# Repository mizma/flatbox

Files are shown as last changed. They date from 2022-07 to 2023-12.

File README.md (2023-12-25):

# Flatbox-ACR

_**No longer maintained.**_

**New Design is available [Here](https://github.com/mizma/ergoSHIFT/) with 11 button support and GP2040-CE firmware support planned**



_**Low profile hitbox-layout fightstick with Acrylic shell**_

This flatbox-acr design is based on [jfedor2/flatbox](https://github.com/jfedor2/flatbox) but with a few tweaks
(rev1.1 pcb has been redone from ground up):

[日本語はこちら](README_ja.md)

* Replaced the 3D printed case with Acrylic shell, allowing to insert printed artwork.
    * or marvel at the simplistic PCB...
    * Heavily inspired by y [Mille-Feuille](https://pomegd.booth.pm/items/2685530) by [@pomegd](https://twitter.com/pomegd)
* modified button layout to:
    * Accomodate for the clearance needed for acrylic cutting
    * To mimic the layout of the original Hitbox button layout(based off of official stencil)
* Silk screen update
    * Added small logo instead of text (flatbox acr)
    * added legends for each buttons (SQUARE, CIRCLE etc.)
    * moved logo to the bottom edge to minimize see-through when adding artwork on top
* Pattern changes
    * GND Fill
    * add vias to join gnd fill
    * moved traces slightly to avoid GND islands and thin GND fills
    * added reset button for Pro Micro board
* Remodeled Button Caps to accomodate for the increased case-height

Final product when assembled will look something like the following:

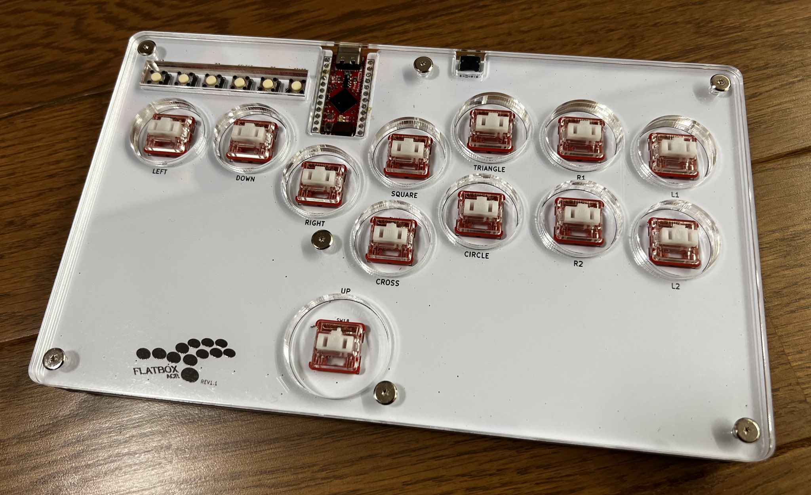
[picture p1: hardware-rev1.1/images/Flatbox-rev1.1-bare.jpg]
Assembled Flatbox


You can print any fan art using the [Stencil](hardware-rev1.1/images/Flatbox-ACR-Stencil_300dpi.png) 
to customize the looks as well.

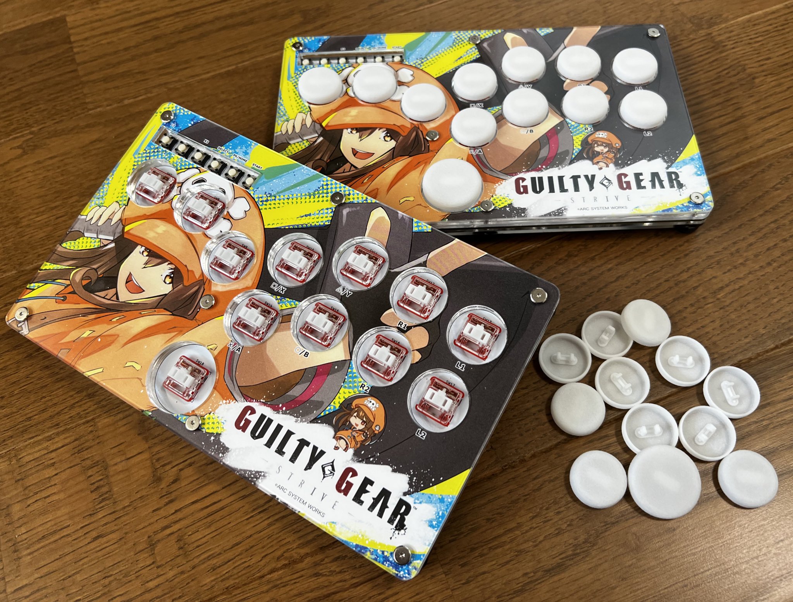
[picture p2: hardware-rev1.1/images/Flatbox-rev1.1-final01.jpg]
Assembled Flatbox with Fan Art


(*) Artwork based on a trace of In-Game Screenshot + Official Fan-kit (©ARK SYSTEM WORKS)

There is currently one revision of the Flatbox-ACR.  They all use Kailh low profile (choc v1) mechanical keyboard switches.
The table below lists their main features.  See the README for each version for details on how to make them.

version | [rev1.1](hardware-rev1.1) |
------- | ------------------------- |
case dimensions | 210x125x13.6mm |
compatibility (using provided firmware) | PC, PS3, Xinput, Switch |
add-on board | Sparkfun Qwiic Pro Micro |
onboard chip | - |
port | USB-C |
SMT assembly required | no |
firmware | [ATmega32U4](firmwares_atmega32u4) |

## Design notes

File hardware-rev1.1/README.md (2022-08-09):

# Flatbox-ACR rev1.1

[日本語はこちら](README_ja.md)

This is rev1.1 of the Flatbox-ACR. In this version an Arduino Pro Micro is soldered onto the main PCB.

To make one you will need:

* [acrylic shell](acrylic-shell)
    * Top layers in 2mm,3mm,2mm thickness
    * Bottom layers in 3mm thickness x 2
* [the Flatbox-ACR PCB](pcb)
* Arduino Pro Micro [SparkFun Qwiic Pro Micro - USB-C (ATmega32U4)](https://www.sparkfun.com/products/15795)
* 12x Kailh low profile (choc v1) switches of your choice
    * I use Kailh Choc v1 Red Pro (Linear and low activation force: 35±10gf with actuation travel: 1.5±0.5mm)
    * Light Blue (gChoc) can be used for even lower actuation force.
* (optionally) 12x Kailh low profile hotswap sockets
* [3D printed buttoncaps](../3d-printed-buttoncaps)
* 6x 6x6x5mm tact switches
    * I Used OMRON B3F-1000 but other similar products with same footprint should work
    * Selecting switches with height higher than 7mm will result in the switch extruding from the case
* 1x 3x6x4.3 horizontal tact switch
    * https://www.newegg.com/p/2S7-01KR-035X0
    * https://shop.yushakobo.jp/collections/all-keyboard-parts/products/a1600ed-01-1
    * [schematics](images/tactile-switch_3x6x4.3.jpg)
* 7x M3 screws (length 20mm)
    * Acryl top 2mm * 2 + 3mm = 7mm
    * PCB 1.6mm
    * Acryl bottom 3mm * 2 = 6mm
    * Rubber feet screw depth = 3mm (using rubber feet below.  adjust for your part)
    * Rubber feet total depth = 8mm (using rubber feet below.  adjust for your part)
    * M3 nut height = 2mm
    * min length = 19.6mm (using rubber feet below.  adjust for your part)
    * max length = 22.6mm (using rubber feet below.  adjust for your part)
* 7x M3 nut and acompanying rubber feet
    * Rubber feet Tochigiya [TM-TK-15](https://www.monotaro.com/p/0933/2486/?displayId=5)
    * The position of the holes are intended for feet radius of less than 8mm
* a soldering iron
    * something with enough power is better 
      (i.e. [Hakko FX 600](https://www.hakko.com/japan/products/hakko_fx600_set.html))
    * I recommend changin tips to D type for most Through-hole soldering, or C type if you plan to
      solder SMT as well. (default B tips are the harder to use for most PCB soldering)
    * Use 230C ~ 250C temp recommended (can be changed if you know your way around)

## Assembly Instructions

### Ordering PCB

I used [JLCPCB](https://jlcpcb.com/).  Just upload the gerber files in [pcb](pcb) and keep most parameters default.
You may change PCB Qty and PCB Color if you like.  All other parameters should be kept the same.

### Ordering 3D Printed Buttons

If you have a 3D printer, print at your own will.  Files are found [here](../3d-printed-buttoncaps/).

* [Flatbox-ACR-ButtonCapBig.stl](../3d-printed-buttoncaps/Flatbox-ACR-ButtonCapBig.stl) 
  is used for the thumb button. 1 board needs 1 of this button.
* [Flatbox-ACR-Buttoncap.stl](../3d-printed-buttoncaps/Flatbox-ACR-ButtonCapBig.stl) is used for all ther buttons.
  1 board needs 11 of this button.
* [Flatbox-ACR-FullSetButtonCaps.stl](../3d-printed-buttoncaps/Flatbox-ACR-FullSetButtonCaps.stl) is an STL file 
  containing 1 full set of buttons (11 small and 1 big.).  If your 3D printing service allows 12 or more shells,
  it may be cheaper to print in one batch using this STL file.
    * Print size needs to be bigger than X：99.0000mm x Y： 93.5000mm x Z： 6.0000mm

Insertion portion may need to be adjusted in size for your 3D Printer and settings to fit snugly to the switch.
You may use some of the printer features but if that doesn't work, you might want to edit the original model.
Model data are found in the same directory in a [FreeCAD](https://www.freecadweb.org/) file format.

Also, since the insertion portion requires a fairly tight tolerance which is not easily achieved by 3D printers.
To that extent, the models are modelled slightly on the larger side.  I have had fairly good results with 
this model using SLS Nylon print but sometimes it is too large.  Which can be filed down to fit.

#### Materials Consideration

* Nylon
    * May be a good place to start for tensile strength and good chemical stability.
    * can be pretty strong if printed using SLS process at some printing services
    * may be prone to warping.  not good for humid places.
* UV Resin
    * Also pretty strong as a material, and stronger to humidity.
    * Maybe slightly more brittle than Nylon

### Ordering Acrylic cuts

I use [Elecrow](https://www.elecrow.com/acrylic-cutting.html) to cut acrylic.

Upload the .zip file in [acrylic-shell](acrylic-shell/) to the Elecrow Acrylic cut service to order.
.Zip file includes the dxf file and the dimentions.txt file.  PDF is just for reference.

Layer 01 and 02 should be made of 3mm thickness.

For the top 3 layers, there are two options:

1. Print Layer 03 at 2mm, 04 at 2mm x 2.
    * This will produce the flatbox-acr at 13.6mm at the body (excl. rubber feet and buttons) at the cost of reset 
      switch not being covered.
2. Print Layer 03 at 2mm, 04 at 3mm and layer 05 at 2mm.
    * This will produce the flatbox-acr at 14.6mm at the body (excl. rubber feet and buttons).  Reset switch will 
      be covered at the cost of thickness and less button extrusion. (may want to tweak the button caps to have 
      more thickness)

The original design file (FreeCAD file) can be found [here](./design_data/acryl-design/).

The Acrylic should look like the following (with PCB stacked)

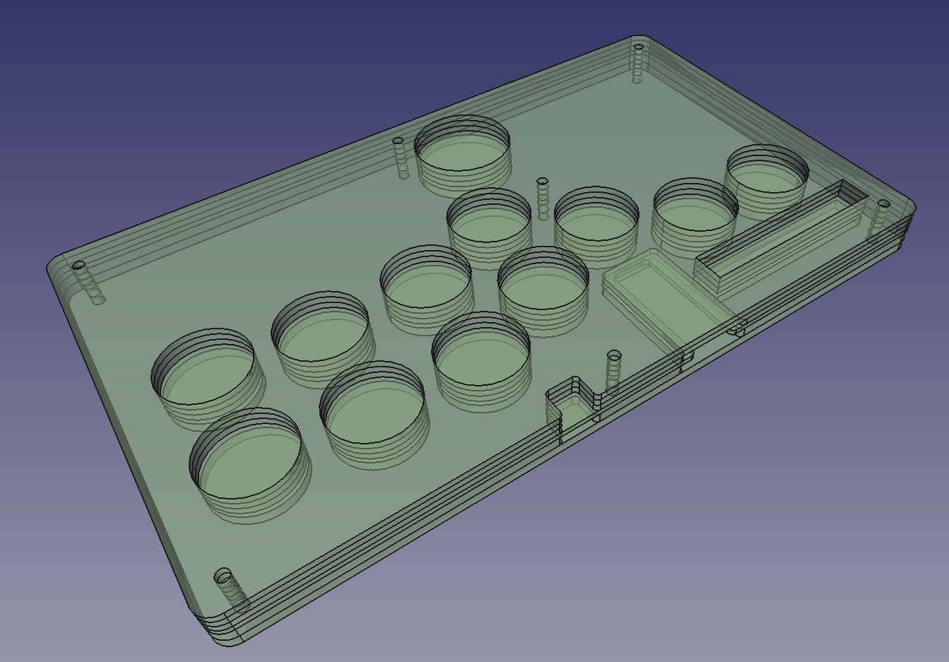
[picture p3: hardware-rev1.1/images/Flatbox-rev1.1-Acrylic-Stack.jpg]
Flatbox-rev1-Acrylic-Stack


(*) Above image uses two Layer 4 at 2mm (exposed reset switch but 1mm thinner)

### Assembly

1. Solder all the Choc v1 switches and the tactile switches.  make sure you populate the side with the logo.
    * If you populate the side with the logo, the parts only goes in in the correct orientation.
    * If you use the hot-swap sockets, those will go on the back. (see silk screen on back side for orientation)
        * For hotswap sockets, pre-solder one side of the pad on PCB, place the socket, heat the pre-solder while
          pressing down on the socket to attach the socket.  After It is attached, solder the other side fully
          and then add more solder on the pre-soldered side.
2. Solder the Pro Micro Qwiic from the bottom side of the PCB up into the slit (USB socket should be between
   the cut-outs on the board, facing up) (Following instruction is how I did it.  There may be other ways)
    1.  First, mask the back side holes on the PCB with masking tape, and poke a small hole in each Through-hole
        with a needle. (This is to stop creating solder filets on the side the ProMicro will be soldered to.
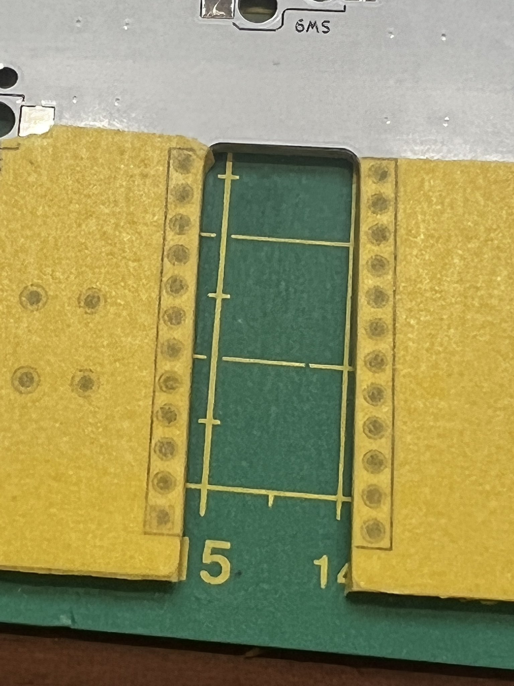
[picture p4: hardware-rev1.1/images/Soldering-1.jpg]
Mask Through-holes
        
    2. Insert a short (2~3cm) tin coated wire in the hole and solder onto the board.  Then cut the excess wire
       on the front side.
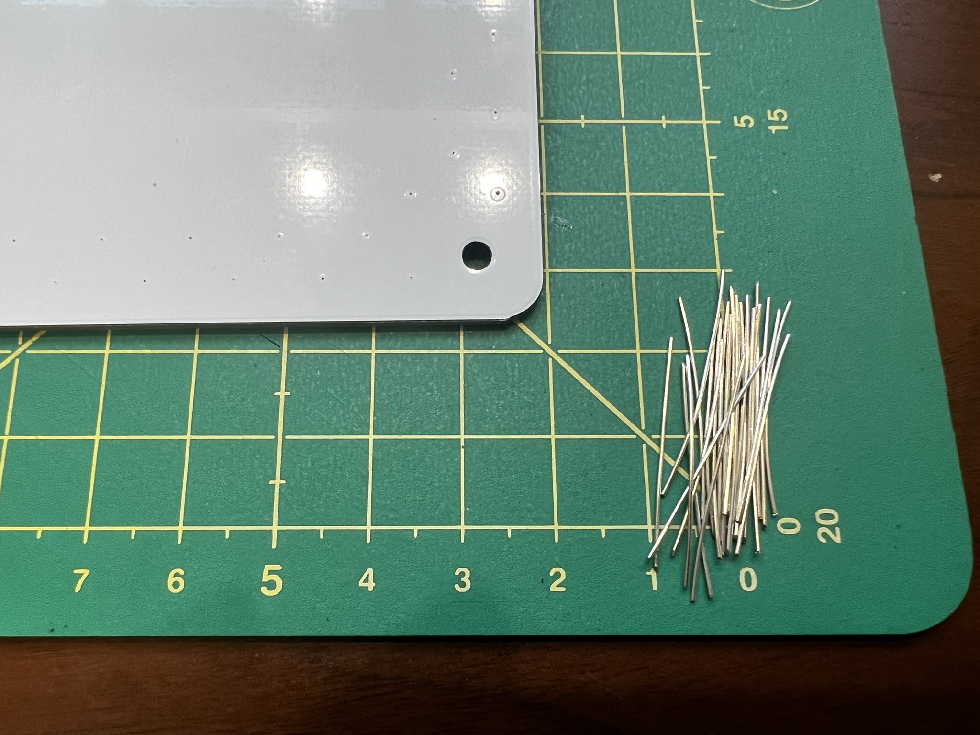
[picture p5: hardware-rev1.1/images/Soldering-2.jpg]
Tin Coated Wires
       
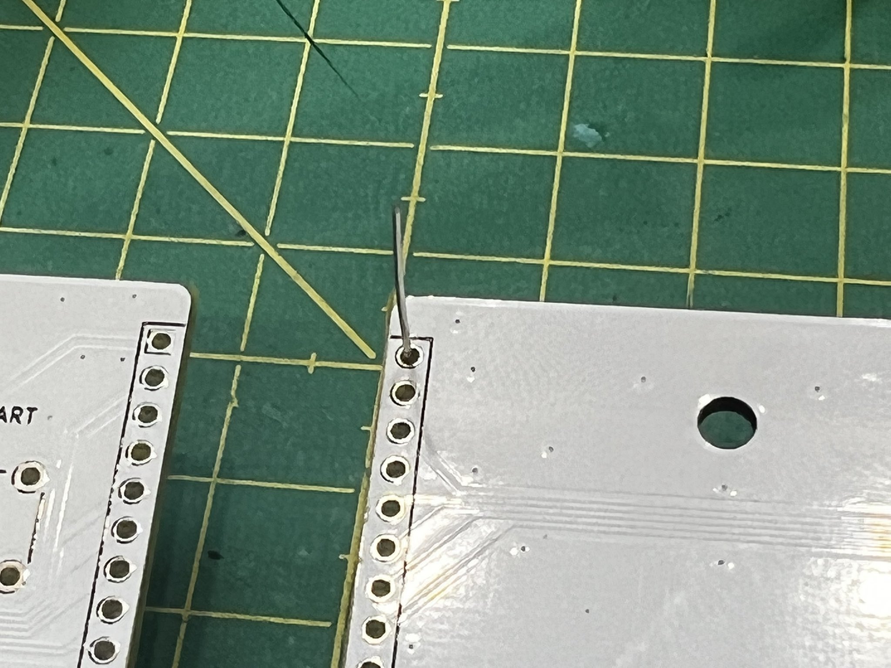
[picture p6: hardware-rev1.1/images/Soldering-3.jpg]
Place Wire
       
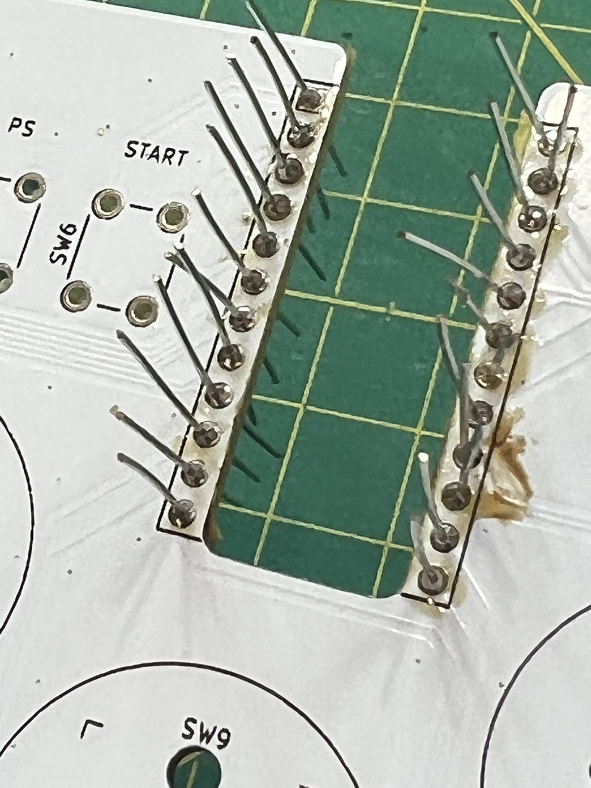
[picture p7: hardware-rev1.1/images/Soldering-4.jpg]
Solder backside
       
    3. Remove the masking tape.  The back side should have a flat solder filled hole with wires coming out 
       the middle.
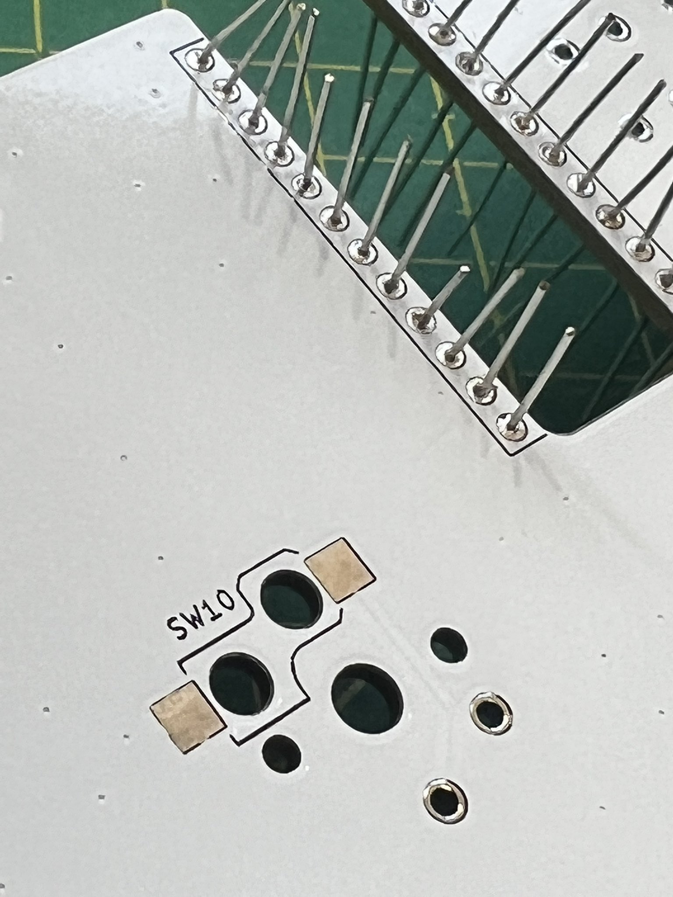
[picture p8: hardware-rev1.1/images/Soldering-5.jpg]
Flat Filled Through-holes
       
    4. Place the Pro-Micro into the wires, tape it down to place.  Also tape the entire front side of 
       the soldered through-holes so the wires don't fall when solder melts.
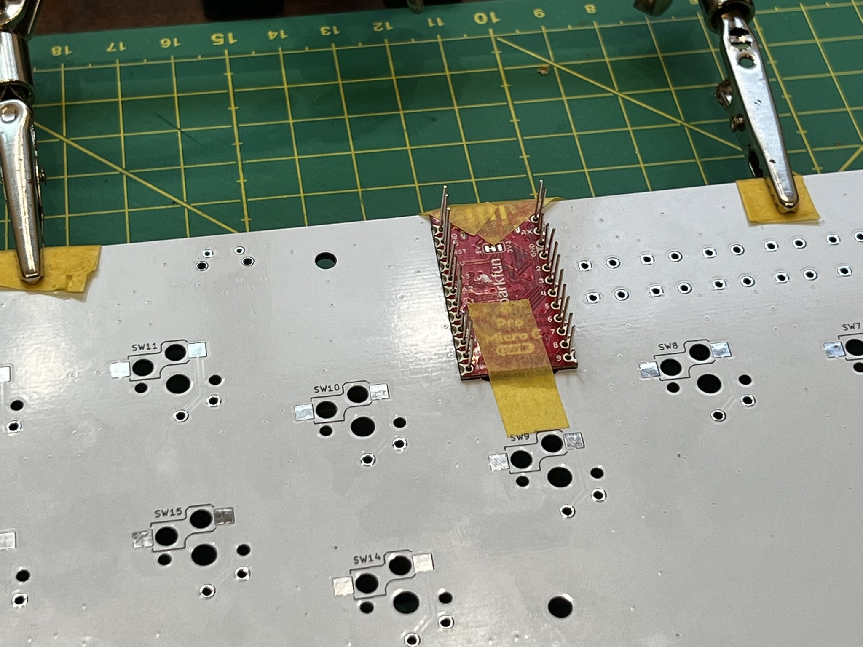
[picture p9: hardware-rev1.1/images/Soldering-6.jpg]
Place Pro-Micro into Wires
       
    5. Solder the Pro-Micro to the tin-coated wire.
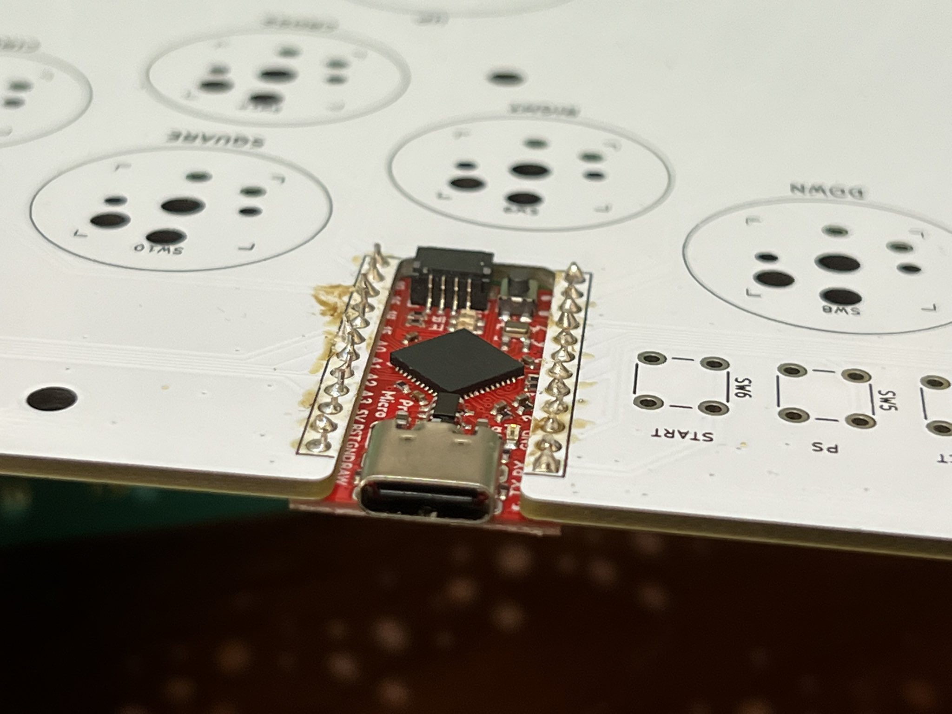
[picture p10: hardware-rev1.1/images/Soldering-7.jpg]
Soldered Pro-Micro
       
3. stack the Acryl and PCB in following order: Layer 01, Layer 02, PCB, Layer 03, Layer 04 and Layer 05.
    * If you use 2 Layer 4s, the order should be 01, 02, 03, 04, 04.
4. Screw on the M3 screws with the nut on all 7 locations.  Rubber feet should be inserted at least in the 4 
   corners between the nut and the acrylic.

It should look like the following when assembled.

Flatbox-rev1.1

### Pro-Tip 1. Filing the Acrylic Edges

Acrylic Edges after laser cutting can be quite sharp and do not feel good.
You may want to file the edges with sandpaper (#400 is a nice place to start) to remove the edges 
on the top acrylic layer so it does not feel bad.

### Pro-Tip 2. Customizing design

You can also insert some artwork below the top acrylic layer as below:

Flatbox-rev1.1_with_artwork1
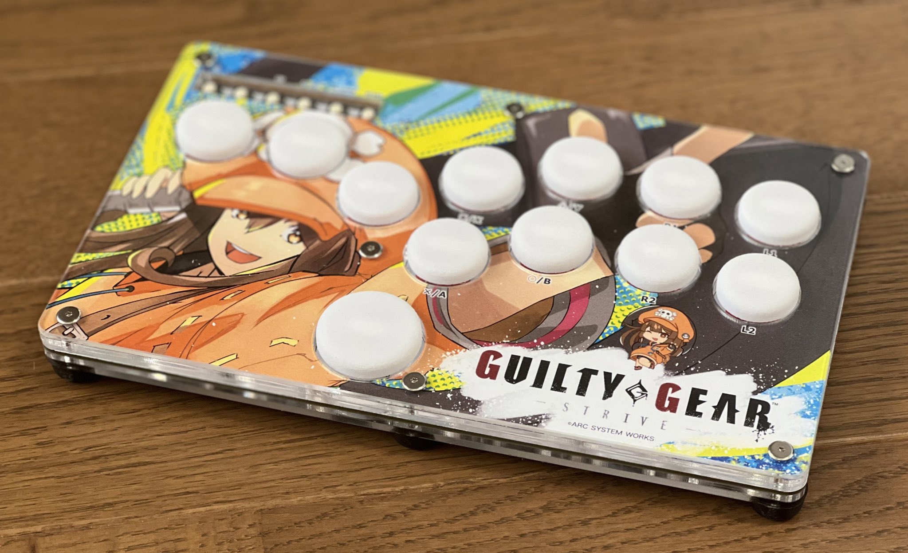
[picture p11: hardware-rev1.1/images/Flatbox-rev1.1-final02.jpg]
Flatbox-rev1.1_with_artwork1

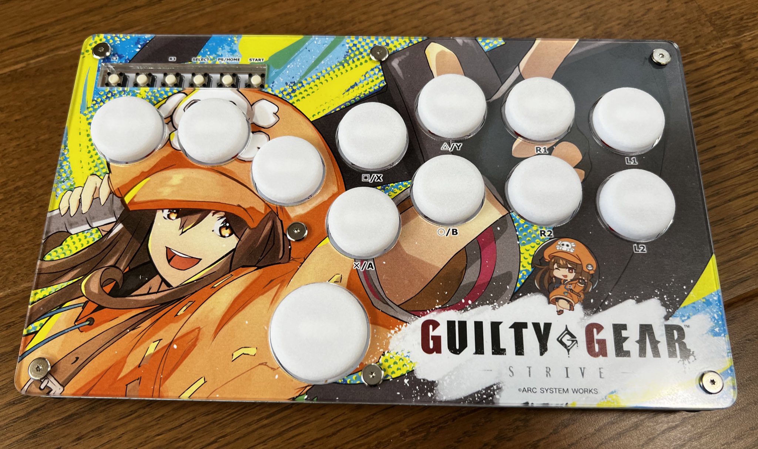
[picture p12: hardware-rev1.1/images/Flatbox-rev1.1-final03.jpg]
Flatbox-rev1.1_with_artwork2


(*) Above sample Artwork based on a trace of In-Game Screenshot + Official Fan-kit (©ARK SYSTEM WORKS)

Stencil for the artwork can be found [HERE](images/Flatbox-ACR-Stencil_300dpi.png).  The stencil is in
300dpi so print the image at 300dpi to adjust size. [Stencil with key labels](images/Flatbox-ACR-Stencil_with_key_label_300dpi.png)
is also available.

To cut the stencil, use one of the top acrylic plates as cutting guides (don't trust the acuracy
of the printed stencil mark, they are good enough to use as design guide, but not acurate enough for 
final cutting guide).  It is easy to cut if you tape the plate on top of the print.

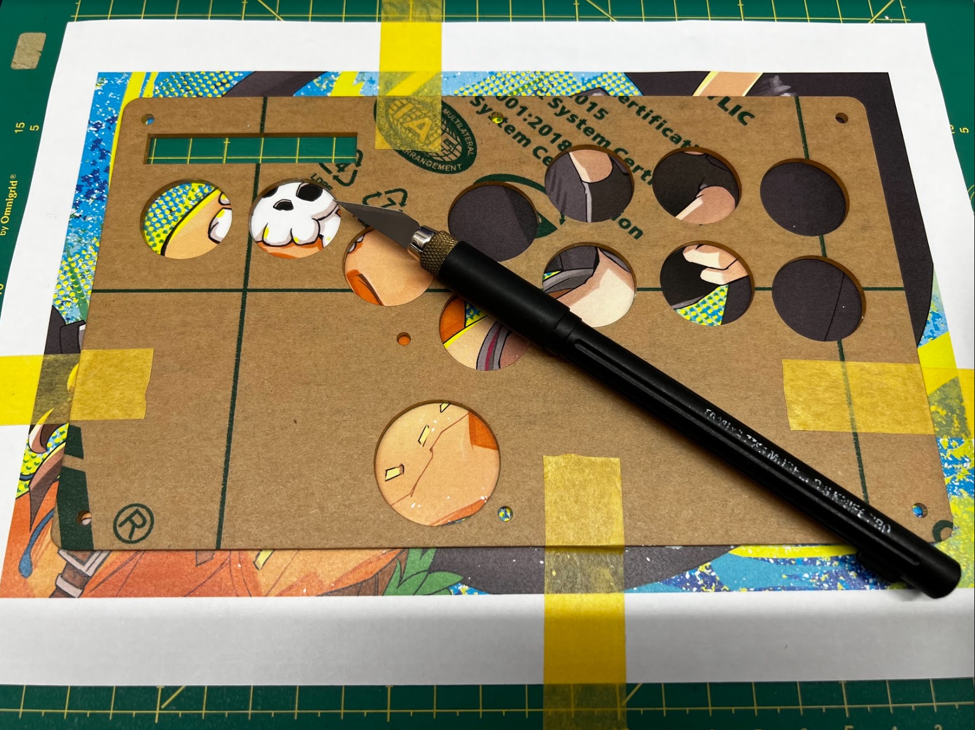
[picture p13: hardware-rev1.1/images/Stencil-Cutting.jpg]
Stencil-Cutting


## License and Acknowlegements

PCB design licensed under [CC BY-SA 4.0](https://creativecommons.org/licenses/by-sa/4.0/) by mizma, derived from
[jfedor2/flatbox](https://github.com/jfedor2/flatbox) rev1.1 as of 2022/07/18

Acrylic sandwitching shell heavily inspired by [Mille-Feuille](https://pomegd.booth.pm/items/2685530) 
by [@pomegd](https://twitter.com/pomegd)

PCB design uses the following libraries or derivatives of the design:

* [jfedor2/flatbox](https://github.com/jfedor2/flatbox) by [jfedor2](https://github.com/jfedor2) ([CC BY-SA 4.0](https://creativecommons.org/licenses/by-sa/4.0/))
* [keyswitches.pretty](https://github.com/daprice/keyswitches.pretty) by [daprice](https://github.com/daprice) ([CC BY-SA 4.0](https://creativecommons.org/licenses/by-sa/4.0/))
* [ProMicroKiCad](https://github.com/Biacco42/ProMicroKiCad) by [Biacco42](https://github.com/Biacco42), derived from [teensy\_library](https://github.com/XenGi/teensy_library) by Ricardo Band ([MIT License](https://opensource.org/licenses/mit-license.php))

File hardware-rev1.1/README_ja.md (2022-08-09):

# Flatbox-ACR rev1.1

Flatbox ACR rev1.1 のリポジトリです。このバージョンでは Arduino Pro Micro をPCBに直接はんだ付けする
形で設計されています。

制作にあたって以下の部品が必要になります：

* [レーザーカットアクリル板](acrylic-shell)
    * PCBより上のレイヤーは2mm, 3mm, 2mmの厚さとなります
    * PCBより下のレイヤーは3mmｘ2枚となります
* [Flatbox-ACR 基盤](pcb)
* Arduino Pro Micro [SparkFun Qwiic Pro Micro - USB-C (ATmega32U4)](https://www.sparkfun.com/products/15795)
* お好きな Kailh ロープロファイル（choc v1）スイッチｘ１２個
    * 作者は Kailh Choc v1 Red Proのリニアタイプのキー（作動圧35±10gf、作動ストローク：1.5±0.5mm）を使用しています
        * アーケードの物に近いのがこちらか更に作動圧の低いリニアタイプになると思います。
    * Light Blue (gChoc)にすることで更に低い作動圧のものにできます
    * choc v2（キーキャップの取り付け部分が＋型のもの）は非対応となります。
* Kailh Low Profile用ホットスワップソケット（必須ではありません）
    * [こちら](https://shop.yushakobo.jp/collections/all-keyboard-parts/products/a01ps?variant=37665172553889)
      で購入できます。ソケットタイプでロープロファイル用を選択してください。
* [ボタンキャップ（3Dプリント）](../3d-printed-buttoncaps)
    * 検証でき次第 DMMマーケット出品予定
* [6x6x5mm タクトスイッチ](https://www.monotaro.com/p/4647/7961/) ｘ6個
    * 上記は OMRON製のB3F-1000ですが、同様のフットプリントの製品であれば代用可能です。
    * 基盤上面から7mm以上のものはケースからはみ出るのでそのあたりを考慮して選択してください。
* 3x6x4.3 水平式タクトスイッチ
    * https://www.newegg.com/p/2S7-01KR-035X0
    * https://shop.yushakobo.jp/collections/all-keyboard-parts/products/a1600ed-01-1
    * [schematics](images/tactile-switch_3x6x4.3.jpg)
* [M3 screws (length 20mm)](https://www.monotaro.com/p/2903/0445/) ｘ7個
    * 上面アクリル厚 2mm * 2 + 3mm = 7mm
    * 基盤厚さ 1.6mm
    * 下面アクリル厚 3mm * 2 = 6mm
    * ゴム足締め付け厚 = 3mm （下記ゴム足利用時）
    * ゴム足全高 = 8mm （下記ゴム足利用時）
    * M3 ナット厚 = 2mm （下記ナット利用時）
    * 最低長 = 19.6mm （下記ゴム足利用時）
    * 最大長 = 22.6mm （下記ゴム足利用時）
* [M3 nut](https://www.monotaro.com/p/6105/4727/) と対応ゴム足 ｘ７個
    * ゴム足は栃木屋の[TM-TK-15](https://www.monotaro.com/p/0933/2486/?displayId=5)に合わせて設計してあります。
* ハンダゴテとハンダ作業に必要な諸々
    * 十分な熱量の物をおすすめします（例 [Hakko FX 600](https://www.hakko.com/japan/products/hakko_fx600_set.html)）
    * ハンダゴテ用チップはD型かC型に変えることをおすすめします（標準で着いてくるB型は電子基板のハンダ作業には
      向いていないため失敗しやすいです）
    * ハンダゴテの温度は利用するハンダに合わせて選択してください。
        * 鉛60%ハンダであれば230℃程度
        * 鉛フリーハンダの場合は270℃程度

## 組み立て方法

### 基盤発注

[JLCPCB](https://jlcpcb.com/) 等で発注してください。[pcb](pcb)にあるzipファイル（ガーバーデータ）を基盤製作会社の
ページでアップロードすれば見積もりが出ます。JLCPCBであれば上記のガーバーデータでそのまま発注可能です。

アップロードしたら発注数と基盤の色はお好みで選択しその他はデフォルトのまま発注してください。

### ３Ｄプリント式ボタンキャップの発注

３Ｄプリンタをお持ちの方は自由にプリントしてご活用ください。STLファイルや元となるCADデータは
[こちら](../3d-printed-buttoncaps/)にあります。

* [Flatbox-ACR-ButtonCapBig.stl](../3d-printed-buttoncaps/Flatbox-ACR-ButtonCapBig.stl) 
  が親指のボタンに使われるキャップになります。一つ必要です。
* [Flatbox-ACR-Buttoncap.stl](../3d-printed-buttoncaps/Flatbox-ACR-ButtonCapBig.stl) がその他のボタンすべてに
  利用されるキャップになります。１１個必要です。
* [Flatbox-ACR-FullSetButtonCaps.stl](../3d-printed-buttoncaps/Flatbox-ACR-FullSetButtonCaps.stl) 
  が、１セットで必要になるボタンキャップを一括プリントするためのSTLファイルになります。プリント時間の短縮や
  プリントサービスでの費用削減に活用ください。
    * こちらをプリントする場合プリントサイズが X：99.0000mm x Y：93.5000mm x Z：6.0000mm 以上に対応している
      必要があります。
    * また、シェル数が１２以上に対応している必要があります。
    * こちらはDMM Makeクリエイターズマーケットで購入できるよう準備中です。

キーキャップとメカニカルキースイッチとの結合部分についてはプリンタのプリント精度等に合わせて調整が必要です。
最悪入らなかったり、ブカブカだったりしてしまうため、利用するプリンタやプリントサービスに合わせて調整してください。
調整する場合は３Ｄプリンタの設定で調整するか、同梱の[FreeCAD](https://www.freecadweb.org/)用設計データを修正してご利用ください。

また、キャップの足部分は現在の３Ｄプリンタでは難しいかなりタイトな精度が求められます。
このため、現状のモデルでは足部分を少し太めに設計してあります。ＳＬＳ方式のナイロン３Ｄプリントではそこそこ
良い結果が出ていますが、稀に太りすぎて挿入できない場合があります。
その場合は紙ヤスリ等で足の部分を徐々に削りながらサイズ調整して利用してください。

#### プリント材料について

* ナイロン（SLS方式）
    * 靭性等も比較的高くこういった部品に適しています
    * 湿度に少し弱いかもしれません
    * プリント精度は結構高め
* 光硬化式レジン
    * ナイロンよりもさらに高い硬度があり靭性も比較的高いです
    * 湿度に対しても強い傾向にあります
    * プリント精度は高いですが、二次硬化処理等の関係で少し太めに出る可能性があります

#### DMM.make クリエイターズマーケット

クリエイターズマーケットから[直接オーダー](https://make.dmm.com/item/1449322/)出来ます。
値段は自分でSTLファイルをアップロードする場合と同じに設定してあります（マージン無し）
審査通った場合はリンクをこちらに貼り付け予定です。

### レーザーカットアクリル板の発注

作者は[Elecrow](https://www.elecrow.com/acrylic-cutting.html)様のサービスを利用しています。

上記サイトを使う場合は[acrylic-shell](acrylic-shell/)に同梱の.zipファイルをアップロードして発注してください。
.zipファイル内には発注に必要なデータ（dxfファイルとdimentions.txt）が入っています。同梱のPDFはあくまで参考です。
別で設計し直して自前でカットする場合はPDFの設計図面を参考にしてください。

Layer 01と02は3mm厚で発注してください。

レイヤー03～05については2パターンの選択肢があります。

1. Layer 03 を 2mm, 04 を 2mm x 2でカット
    * この方法の場合全体厚が1mm薄くできる代わりにリセットボタン部分の上面がアクリル板で覆われない状態になります。
      この方式ではレイヤー04を二枚重ねて使います。
2. Layer 03 を 2mm, 04 を 3mm , layer 05 を 2mmでカット
    * この方式の場合、方式１よりも1mm分厚くなりますがリセットボタン部分の上面をアクリル板で覆うことが可能です。
      ３Ｄプリントキーキャップはこちらの方式を前提に設計しています。

オリジナルの設計データは[こちら](./design_data/acryl-design/)にあります（FreeCAD用ファイル）

アクリル板とPCBをスタックした場合以下の様になります。

Flatbox-rev1-Acrylic-Stack

(*) 上記イメージでは Layer 4 を 2mm でカットしたものを二枚重ねたパターンです

### 組み立て

1. Pro Micro Qwiic USB-Cを、基盤の下側からスリットに嵌まるようにはんだ付けします（USBソケットが基盤の切り込みの
   間に来るように取り付けます）。以下の手順は作者の手法ですが他にもやり方は色々あると思うのでご自分のやりやすい
   方法を使ってみてください。
    1. まず、PCBの下面（ロゴの無い方）のスルーホールをマスキングテープで塞ぎ、安全ピン等の針で各スルーホールの
       中心に穴を空けます（こうすることでリードをハンダ付けしたときにPro Micro取り付け側にフィレットが形成される
       のを防ぎ、Pro Microをぴったりくっつけてハンダ付けできます）。
       Mask Through-holes
    2. ２～３cm程にカットした[錫メッキ軟銅線](https://www.monotaro.com/p/0523/4303/)を各穴に差し込んで表側から
       はんだ付けし、余分なリードをカットします。
       Tin Coated Wires
       Place Wire
       Solder backside
    5. マスキングテープを剥がします。基盤裏側が基盤表面いっぱいいっぱいまでハンダが流れ込み、平らになっている
       事を確認してください。（あまりにもハンダが流れていない場合ははんだ付け時にスルーホール側をきちんと熱し
       切れていない為に起こります。壊れる部品も無いので焦らずじっくりハンダゴテで熱してからハンダを流し込む
       用作業しましょう。特にGNDピンはGNDフィル部分に熱が持っていかれるので余分に熱する必要があります。）
       Flat Filled Through-holes
    6. Pro Microを基盤裏側に生やしたピンにはめ込み、マスキングテープで固定します。また、表面のカットしたピン
       をカバーするようにマスキングテープを貼り付けます（Pro Microをはんだ付けする際にまたリードを熱するため
       基盤側のハンダも溶けます。その際にピンが抜け落ちないよう抑えるためにマスキングテープで止めます）。
       Pro Microをピンに通す前にピンをすべてまっすぐに伸ばしておくと作業がしやすいです。後は長いリードから
       順に穴にはめ込み、引っかかったら引っかかったピンをピンセット等でずらしながら順番にスルーホールに通せば
       嵌め込むことが出来ます。
       Place Pro-Micro into Wires
    7. リードにPro Microをはんだ付けします。
       Soldered Pro-Micro
2. タクトスイッチとChoc v1スイッチを基盤表面にハンダ付けします。
    * すべて表面に差し込めば正しい方向にしかはんだ付け出来ないようになっています。
    * ホットスワップソケットを使う場合はホットスワップソケットを基盤裏面に実装してください（シルクのアウトライン
      に合うように部品を設置すればOKです）
        * ホットスワップソケットをハンダ付けする場合
            1. まず基盤側のソケット用ハンダパッドの片側に少しだけ予備ハンダをつけます。
            2. ホットスワップソケットを基盤に差し込み上から押さえつけながら予備ハンダのついた側をハンダゴテで
               熱し、仮付します。
            3. 仮付け指定ない側をハンダ付けし、その後仮付けした側に追加でハンダ付けして完全に固定したら完了です。
3. アクリル板とPCBを次の順序で重ねます： Layer 01, Layer 02, 基盤, Layer 03, Layer 04 and Layer 05.
    * Layer 4を二枚使う場合は： 01, 02, 基盤, 03, 04, 04 の順序になります。
4. M3ネジとゴム足、M3ナットを使って7箇所の固定穴を留めます。

この時点で以下のような形になるはずです。

Flatbox-rev1.1

5. 最後に３Ｄプリントしたキーキャップを取り付けて完成

### おすすめ作業その 1. アクリル板の角落とし

レーザーカットされたアクリル板の角はかなりエッジが立っており利用時に手のひらにあたって痛いので
紙やすり（４００番か２００番あた）で角をヤスリがけすると角が落ちて痛くなくなります。

### おすすめ作業その 2. 痛アケコンカスタム

以下のようにアクリル板の間にアートワークを差し込むことが可能です。

Flatbox-rev1.1_with_artwork1
Flatbox-rev1.1_with_artwork1
Flatbox-rev1.1_with_artwork2

(*) 上記の作例はギルティギアストライブのゲーム内キャプチャをトレースして作成したイラストとオフィシャル
ファンキットを利用しています。(©ARK SYSTEM WORKS)

差し込みアート用のステンシルは[こちら](images/Flatbox-ACR-Stencil_300dpi.png)にあります。
ステンシルは300dpiで作成しているため、印刷時に300dpiで印刷することで概ねサイズが合う形で印刷されます
（印刷精度の関係でピッタリにはならないです）。
また[こちらのステンシル](images/Flatbox-ACR-Stencil_with_key_label_300dpi.png)を使えばPCB基盤にある
スイッチのラベルも含めた形で印刷可能です。

印刷したステンシル付きアートワークをカットする際は印刷されたステンシルガイドを使わずに、Layer 5の
アクリル板を使ってカットしてください（プリンターの印刷精度はそこまで高くないためずれてしまいます）。
カットする際はカッティングボードの上に印刷物とアクリル板をマスキングテープ等で固定すると作業がやりやすいです。

Stencil-Cutting

## ライセンスと謝辞

この基盤は@mizmaにより[クリエイティブ・コモンズ 表示 - 継承 4.0 国際 ライセンス](https://creativecommons.org/licenses/by-sa/4.0/)の下に提供されています。
設計は ２０２２年７月１８日にフォークされた[jfedor2/flatbox](https://github.com/jfedor2/flatbox) rev1.1をベースに
作成されています。

アクリル板サンドイッチ方式は[@pomegd](https://twitter.com/pomegd)様の[Mille-Feuille](https://pomegd.booth.pm/items/2685530) を参考に製作されています。

基盤設計では以下のライブラリや設計を参考にさせていただいております：

* [jfedor2/flatbox](https://github.com/jfedor2/flatbox)。[jfedor2](https://github.com/jfedor2)様作 ([CC BY-SA 4.0](https://creativecommons.org/licenses/by-sa/4.0/))
* [keyswitches.pretty](https://github.com/daprice/keyswitches.pretty)。[daprice](https://github.com/daprice)様作 ([CC BY-SA 4.0](https://creativecommons.org/licenses/by-sa/4.0/))
* [ProMicroKiCad](https://github.com/Biacco42/ProMicroKiCad)。[Biacco42](https://github.com/Biacco42)様作
    * [teensy\_library](https://github.com/XenGi/teensy_library) Ricardo Band様作
      ([MIT License](https://opensource.org/licenses/mit-license.php))ベースに作成

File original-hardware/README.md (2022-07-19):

# Flatbox: Low profile hitbox-layout fightstick

**NOTE: This is the original design files as it was forked on 2022/07/18.  For the latest design, refer to [jfedor2/flatbox](https://github.com/jfedor2/flatbox)**

This repository contains 3D-printable models, PCB design files and code needed to make an arcade controller that looks like this:

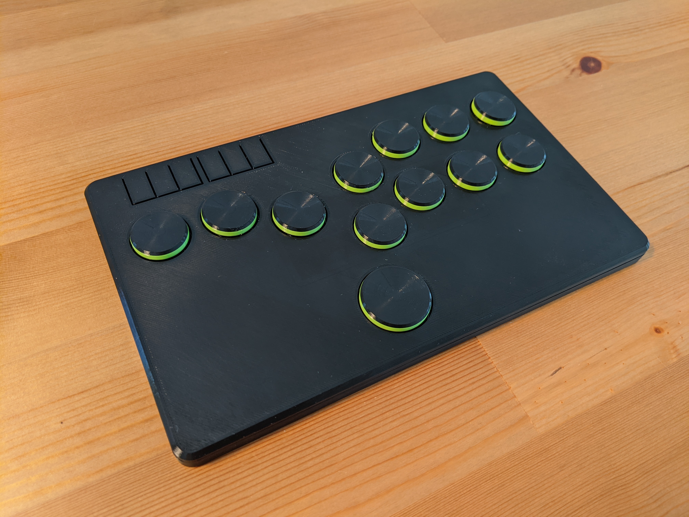
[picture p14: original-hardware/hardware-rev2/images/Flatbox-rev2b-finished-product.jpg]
Assembled Flatbox


There are four major versions of the Flatbox. They all use Kailh low profile (choc v1) mechanical keyboard switches. The table below lists their main features. See the README for each version for details on how to make them.

version | [rev1.1](hardware-rev1.1) | [rev2](hardware-rev2) | [rev3](hardware-rev3) | [rev4](hardware-rev4)
------- | ------------------------- | --------------------- | --------------------- | ---------------------
case dimensions | 218x128x10mm | 218x130x10mm | 218x130x10mm | 218x130x10mm
compatibility (using provided firmware) | PC, PS3 | PC, PS3 | PC, PS3, PS4 | PC, PS3
add-on board | Arduino Pro Micro | - | [Brook PS3/PS4](https://www.brookaccessory.com/detail/58690501/) | -
onboard chip | - | ATmega32U4 | - | RP2040
port | micro USB | USB-C | USB-C | USB-C
SMT assembly required | no | yes | yes | yes
firmware | [ATmega32U4](firmware-atmega32u4) | [ATmega32U4](firmware-atmega32u4) | [Brook](https://www.brookaccessory.com/download/PS3/) | [RP2040](firmware-rp2040)

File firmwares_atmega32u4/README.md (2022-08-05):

# ATMEGA32U4 Firmwares

[日本語はこちら](README_ja.md)

There are currently two firmwares that is customized to work with ATMEGA32U4 5V AVR version of the Flatbox ACR boards (3.3V board are not supported).

Both controllers should work similarly in terms of SOCD cleaning configuration and Up/Down inversion configuration.

Firmware            | [DINPUT](DINPUT)      | [LUFA](LUFA)          |
------------------- | :-------------------: | :-------------------: |
DInput              | **YES**               | NO                    |
XInput              | NO                    | **YES**               |
PS3                 | **YES**               | NO                    |
Switch              | NO                    | **YES**               |
SOCD                | Hitbox,Gafro,NEUTRAL  | Hitbox,Gafro,NEUTRAL  |
Vertical Inversion  | **YES**               | **YES**               |
DPAD emulation      | **YES**               | **YES**               |
Fake Left Stick     | NO                    | **YES**               |
Fake Right Stick    | NO                    | **YES**               |

## Configuration

All following settings are persistent and will be kept over power cycles or resets.

| Firmware | | DINPUT | LUFA |
| :--- | :---: | :---: | :---: |
| Up/Down Inversion | Normal | Down + Reset | Down + Reset |
| | Invert | Up + Reset | Up + Reset |
| SOCD Cleaning | Hitbox mode | R3(RS) + Reset | R3(RS) + Reset |
| | Gafro Mode | L3(LS) + Reset | L3(LS) + Reset |
| | Neutral Mode | PS(HOME) + Reset  | PS(HOME) + Reset |
| Change Input Mode | Xinput | Not Supported | "Start" + Reset |
| | Switch | Not Supported | "Select" + Reset |
| | DInput/PS3 | Default | Not Supported |
| Direction Mode | DPAD | Default | UP+START+SELECT |
| | Left Analog Stick | Not Supported | LEFT+START+SELECT |
| | Right Analog Stick | Not Supported | RIGHT+START+SELECT |

For Key Combos using Reset, Reset should be clicked once while holding the other input.
Wait for the controller to reset and connect to the PC/Console before releasing the input.

You can print [this cheat sheet](Flatbox-ACR_Hotkey_Cheatsheet.pdf) to insert in the back
of your Flatbox-ACR (PageSize: B5)

## [DINPUT](./DINPUT/)

This firmware is based on the original Flatbox firmware and is configured to work as Dinput device.
Simple firmware to work on if you only need Dinput support or want to connect it to PS3 
(Should work as PC Dinput and PS3 controller).

## [LUFA](./LUFA/)

This firmware is based on the [LUFAHybridFightstick](https://github.com/CrazyRedMachine/LUFAHybridFightstick) by [CrazyRedMachine](https://github.com/CrazyRedMachine)
and supports XInput mode and Switch controller mode (gets detected as Pokken Controller).

This firmware can be switched between Xinput (consoles not supported, only PCs) mode and Switch controller mode.

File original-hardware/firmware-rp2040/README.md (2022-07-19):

This is code for a USB arcade controller, meant to be used with RP2040-based boards.

It works with Flatbox [rev4](../hardware-rev4). There's a precompiled UF2 [binary](../hardware-rev4/firmware/flatbox-rev4.uf2) included.

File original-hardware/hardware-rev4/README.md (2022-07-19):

# Flatbox rev4

This is rev4 of the Flatbox. In this version the PCB includes a microcontroller and USB port. Everything is built in, you only have to add the switches (and flash the firmware).

To make one you will need:

* [3D printed case parts](3d-printed-case) - top and bottom
* [the PCB](pcb)
* 12x Kailh low profile (choc v1) switches of your choice
* (optionally) 12x Kailh low profile hotswap sockets
* [3D printed buttoncaps](../3d-printed-buttoncaps)
* 6x 6x6x5mm tact switches
* 7x 3x10mm wood screws
* some kind of rubber feet or non-slip padding for the bottom
* a soldering iron

I printed the case at 0.20mm layer height. The top part should be printed upside-down, the bottom part should be printed as-is. They don't require supports.

I used [JLCPCB](https://jlcpcb.com/) to make the PCB and assemble the SMD parts. The [included files](pcb) can be used with JLCPCB directly. If you want to use some other service, check the file formats that they expect. When ordering from JLCPCB, upload the Gerber zip, leave all the settings at default (you can choose the PCB color), then select "SMT Assembly" and upload the BOM and CPL files. PCB thickness should be 1.6mm.

The PCB you get from JLCPCB will look like this:

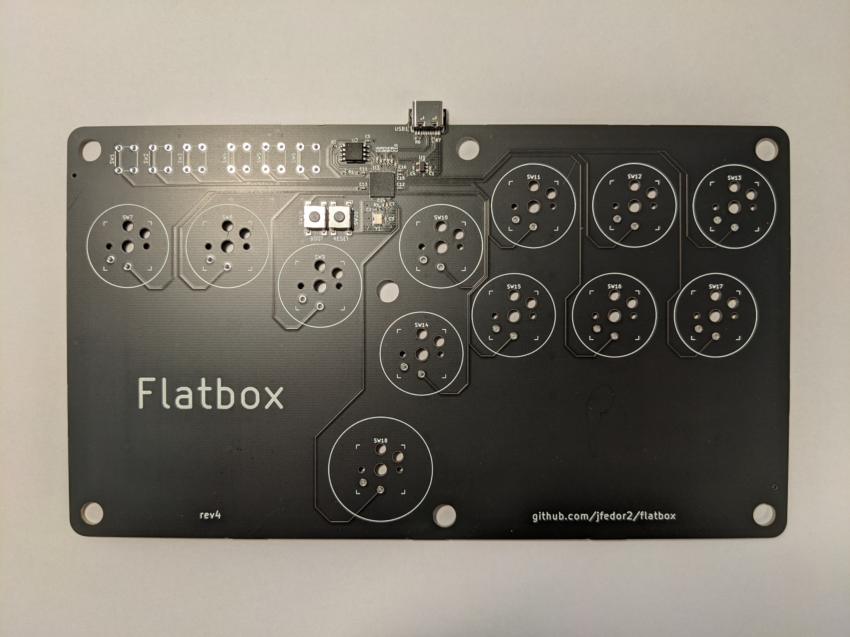
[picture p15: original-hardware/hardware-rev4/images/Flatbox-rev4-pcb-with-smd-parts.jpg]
Flatbox rev4 PCB with SMD parts assembled


The switches can be soldered in directly to the PCB or you can use hotswap sockets. If you want to use hotswap sockets, you will have to print the appropriate bottom part of the case (it's 1mm thicker).

You don't have to use the [code](../firmware-rp2040) included here, you can use any other RP2040-compatible firmware. The included firmware works with the PS3 and PC.

To flash the firmware, connect the PCB to a computer with a USB cable, then press the RESET button while holding the BOOT button on the PCB. A drive named "RPI-RP2" should appear. Copy the [flatbox-rev4.uf2](firmware/flatbox-rev4.uf2) file to that drive. That's it.

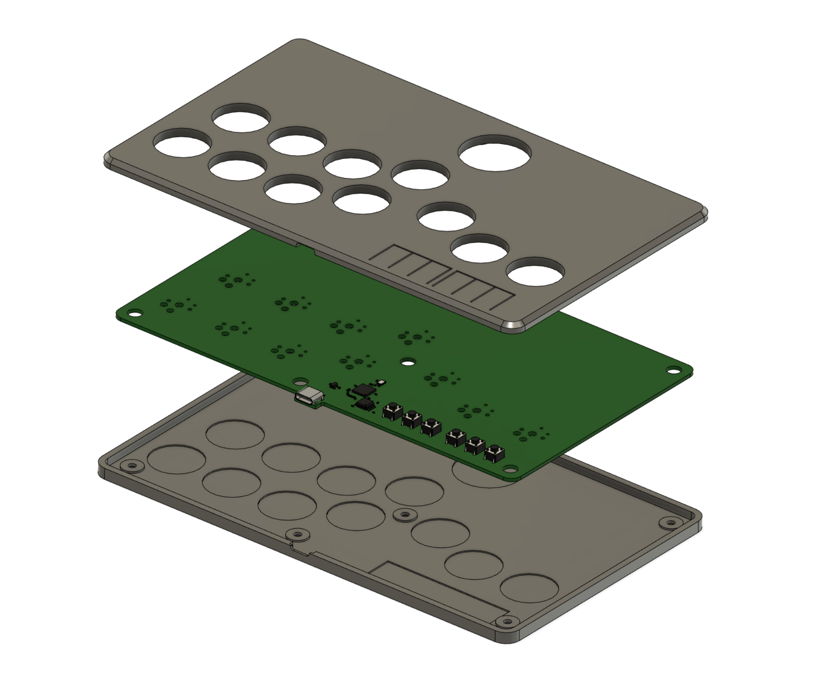
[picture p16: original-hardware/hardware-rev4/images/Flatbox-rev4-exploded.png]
Flatbox rev4 exploded view of the 3D printed case


PCB design licensed under [CC BY-SA 4.0](https://creativecommons.org/licenses/by-sa/4.0/).

PCB design uses the following libraries:

* [keyswitches.pretty](https://github.com/daprice/keyswitches.pretty) by [daprice](https://github.com/daprice) ([CC BY-SA 4.0](https://creativecommons.org/licenses/by-sa/4.0/))
* [Type-C.pretty](https://github.com/ai03-2725/Type-C.pretty) by [ai03-2725](https://github.com/ai03-2725)
* RP2040 library from the [minimal design example](https://datasheets.raspberrypi.org/rp2040/Minimal-KiCAD.zip) from the [Hardware design with RP2040](https://datasheets.raspberrypi.org/rp2040/hardware-design-with-rp2040.pdf) document

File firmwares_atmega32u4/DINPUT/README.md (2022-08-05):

[日本語はこちら](README_ja.md)

This is Arduino code for a USB arcade controller, meant to be used with ATmega32U4-based boards like the Arduino Pro Micro.

It works with Flatbox-ACR [rev1.1](../hardware-rev1.1)

## Change Points from [original](https://github.com/jfedor2/flatbox/blob/master/firmware-atmega32u4)

* Implemented SOCD Cleaner with selection of Hitbox style and Gafro-Controller style cleaning
    * Hold R3 when connecting to set to Hitbox Style SOCD Cleaner
    * Hold L3 when connecting to set to Gafro-controller style SOCD Cleaner
    * Hold PS when connecting to set to All Neutral SOCD Cleaner
    * Settings are saved in EEPROM so it will not change after power cycle
* Implement Up/Down Inversion (for playing normal arcade games)
    * Hold DOWN to set to Hitbox style
    * Hold UP to invert Up and Down buttons.
    * Settings are saved in EEPROM

## Building Instructions

- Download Arduino IDE, 
- Download the Bounce2 Library inside the Arduino IDE
- Add `https://github.com/CrazyRedMachine/Arduino-Lufa/raw/master/package_arduino-lufa_index.json` as an Additional Board Manager URL (in `File -> Preferences` menu)
- Install LUFA AVR Boards from the Board Manager
- Select Arduino Leonardo (LUFA) as your board type (Pro-Micro is a compatible board to Leonardo)
- Upload the code and Have Fun

### How to upload

When you reflash AVR boards with USB HID device software, Arduino IDE cannot automatically reset and flash the software.
You will need to press reset button on the AVR board (SW_RST1 on Flatbox ACR) to put it into Bootloader mode to reflash.
When you use Sparkfun Qwiik ProMicro 5V, you will need to double-click the reset button to put it into Bootloader.

I recommend setting up VSCode Arduino plugin.  If you open this directory with VSCode, it is already set up so all you need to do is
run Arduino: Verify from the command pallet (You will still need to install Arduino, Bounce Library and add the LUFA board manager URL before you can run verify).
The .hex file will be created in the Build folder.

Take the .hex file and use [QMK Toolbox](https://github.com/qmk/qmk_toolbox) to flash the .hex file.

In QMK Toolbox, Press OPEN and select the .hex file you just created, (or just use the one in the repository).  Select ATMega32U4 from the dropdown menu at the top right corner.
Click the Reset button on the Pro-Micro (Double-Click on Qwiik ProMicro USB-C variant).  When you see the "Caterina device connected (usbser): ~~~" text, press Flash button.

This method, while requires extra software setups, is more reliable than trying to time the Reset while Arduino IDE is doing it's thing...

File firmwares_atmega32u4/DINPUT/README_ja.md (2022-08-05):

こちらのファームはArduino Pro Micro 等のATMega32u4ベースの制御基盤で利用するためのファームになります。

Flatbox-ACR [rev1.1](../hardware-rev1.1) に利用できます。

## [オリジナル](https://github.com/jfedor2/flatbox/blob/master/firmware-atmega32u4)からの変化点

* SOCDクリーナー設定機能の追加（ヒットボックスモード、ガフロコンモード、全ニュートラルモード対応）
    * 接続時／リセット時にR3を押すとHitbox風SOCDクリーナーになります
    * 接続時／リセット時にL3を押すとガフロコン風SOCDクリーナーになります
    * 接続時／リセット時にPSを押すと全ニュートラルモードになります。
    * 設定はEEPROMに保存され電源を切っても保持されます。
* 上下反転モード機能の追加（格ゲー以外のゲーム用）
    * 接続時／リセット時にDOWNキーを押すとヒットボックス風のレイアウトになります
    * 接続時／リセット時にUPキーを押すと上下キー反転になります。
    * 設定はEEPROMに保存され電源を切っても保持されます。

## ファームウェアビルド手順

1. [Arduino IDE](https://www.arduino.cc/en/software)をダウンロードしてインストールしてください。
2. Arduino IDE内のライブラリ管理メニューからBounce2ライブラリをインストールしてください。
3. ファイル→環境設定から追加のボードマネージャURLに
   `https://github.com/CrazyRedMachine/Arduino-Lufa/raw/master/package_arduino-lufa_index.json` を追加。
4. ツール→ボード→ボードマネージャからLUFA AVR Boardをインストール
5. ツール→ボード以下で Arduino Leonardo (LUFA) を選択
    * Pro-MicroはArduino Leonardoの互換ボードなのでこちらで動作します
6. マイコンボードに書き込みで書き込み出来ます。
    * 初回の書き込みは特に何もしなくても上記設定をして付属の.inoを書き込めば書き込めますが2度め以降は
      書き込み出来ません。これはHIDモードで動作するファームはArduino IDEからのリセット要求に対応できない
      ためです。2回め以降の書き込みを行う場合は Arduino IDE で書き込みボタンを押してからログで
      PORTS {} / {} => {} といったような内容が出力され始めた段階でリセットボタンを押下（Pro-Micro Qwiic
      の場合はリセットボタンをダブルクリック）することで書き込みが出来ます。
    * 上記ログを表示するためには Arduino IDE の環境設定で「より詳細な情報を表示する」にチェックを入れると
      出ます
    * タイミングが難しい場合は以下に記載している .hex ファイルを取り出して QMK Toolbox で書き込みする方法も
      あります。

### ファームの書き込み方法

USB HID対応のファームをAVRボードに書き込みすると、Arduino IDEから書き込み時の自動リセットを受け付けなくなります。
一度ファームを書き込んだ後は書き込み処理時に手動でリセット（Flatbox ACRではSW_RST1）を押す必要があります。
Sparkfun Qwiic Pro Micro 5Vを使った場合はリセットをダブルクリックすることで書き込みモードに入れることが出来ます。

Arduino IDEでは自分で書き込みのタイミングを制御出来ないため、2回目以降はVSCodeのArduinoプラグインを使って
コンパイルだけ行い、.hex ファイルを取り出して [QMK Toolbox](https://github.com/qmk/qmk_toolbox)を利用して
書き込む方法がおすすめです。
VSCodeは[こちら](https://azure.microsoft.com/ja-jp/products/visual-studio-code/)からダウンロードできます。
インストールが終わったらプラグインからArduinoを検索しマイクロソフト製のArduinoプラグインをインストール。
Arduino IDEで上記の設定が一通り終わった後にこのフォルダをVSCodeで開くことでVSCodeからのコンパイルが可能です。
.inoファイルを開いてVSCodeのコマンドパレットから Arduino: Verify を選択するとコンパイルされ、buildフォルダに
.hexファイルが生成されます。

.hexファイルは[QMK Toolbox](https://github.com/qmk/qmk_toolbox)を使って書き込みが出来ます

1. QMK Toolboxを起動したら、右上のOPENから上記で作成した.hexファイルを選択してください。
2. 右上のドロップダウンから ATMega32u4を選択してください
3. Pro Micro のリセットボタンを押し（Qwiic Pro Micro USB-Cの場合はリセットをダブルクリックし）、QMK Toolbox
   のログ上に黄色の文字で"Caterina device connected (usbser): ~~~"と出たら右上のFlashボタンを押下すると
   書き込みが開始されます。書き込み完了後に自動でボードがリセットされ新しいファームで立ち上がります。

こちらの方法は追加のソフトのセットアップが必要ですが、コンパイルと書き込みを分けて行えるため、リセットのタイミング
が図りやすいため失敗し辛い為おすすめです（ただし初回書き込みはArduino IDEでないとうまくいかない事があったため、
新品のPro Microを書き込む場合はArduino IDEで行う事をおすすめします）

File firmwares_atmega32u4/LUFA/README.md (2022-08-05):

[日本語はこちら](README_ja.md)

## LUFA Switch/XInput hybrid Fightstick firmware

This firmware is a derivative of the awesome [LUFAHybridFightstick](https://github.com/CrazyRedMachine/LUFAHybridFightstick) by [CrazyRedMachine](https://github.com/CrazyRedMachine)

## Acknowledgments

This work is a fork of [LUFAHybridFightstick](https://github.com/CrazyRedMachine/LUFAHybridFightstick) by [CrazyRedMachine](https://github.com/CrazyRedMachine) and
is based on [fluffymadness' ATMega32U4-Switch-Fightstick](https://github.com/fluffymadness/ATMega32U4-Switch-Fightstick)
and [bootsector's XInputPadMicro](https://github.com/bootsector/XInputPadMicro), with a QoL features added by CrazyRedMachine.

This fork is customized for the needs of Flatbox-ACR features

* Remapped keys to work with Flatbox-ACR layout
* Removed support for analog stick
* reorganized the customization button settings for SOCD and other features
    * SOCD config is now only at startup and only provide three common modes (All Neutral, Hitbox and Gafro)
    * Added feature to configure vertical input inversion.  Useful when using Hitbox layout on non-fighting games.

## Features

### Gamepad modes

Hold "select" as you plug the controller to make it a Nintendo Switch controller.

Hold "start" as you plug the controller to make it an XInput controller.

Gamepad mode is persistent across plugging and unplugging the controller, so if you don't press anything while plugging the controller, it will stay in the last used mode. 

### DPAD modes

You can switch seamlessly between the 3 stick modes by pressing START+SELECT+(LEFT/UP/RIGHT)

- UP: DPAD 
- LEFT: Fake Left Analog (DPad is mapped to L-Analog)
- RIGHT: Fake Right Analog (DPad is mapped to R-Analog)

DPAD mode is also persistent.

### Real analog support

This function has been removed since Flatbox-ACR has no plans of adding analog inputs

### Simulated home button

This is also removed since we have custom hardware that support home buttons

### SOCD Cleaning

* HOME at startup = All NEUTRAL
* RS at startup = Hitbox style SOCD cleaning (Up+Down=Up, Left+Right=Neutral)
* LS at startup = Gafro style SOCD cleaning (Up+Down=Up, Left+Right=Last Input)

You can use the Reset button on the Flatbox-ACR while holding the buttons above to change mode.

### UP-DOWN inverse

Since Flatbox-ACR is a Hitbox style controller, Up and Down button layout is a little convoluted for normal use outside its fighting game use-case.
I have added inverting the UP/DOWN input as a feature so the controller can be used a little easier on normal games... (although it still feels a little unweildy TBH.)

* To invert UP and DOWN inputs, press UP at startup.
* To set to normal mode, press DOWN at startup.

## Building Instructions

- Download Arduino IDE, 
- Download the Bounce2 Library inside the Arduino IDE
- Add `https://github.com/CrazyRedMachine/Arduino-Lufa/raw/master/package_arduino-lufa_index.json` as an Additional Board Manager URL (in `File -> Preferences` menu)
- Install LUFA AVR Boards from the Board Manager
- Select Arduino Leonardo (LUFA) as your board type (Pro-Micro is a compatible board to Leonardo)
- Upload the code and Have Fun

### How to upload

When you reflash AVR boards with USB HID device software, Arduino IDE cannot automatically reset and flash the software.
You will need to press reset button on the AVR board (SW_RST1 on Flatbox ACR) to put it into Bootloader mode to reflash.
When you use Sparkfun Qwiik ProMicro 5V, you will need to double-click the reset button to put it into Bootloader.

I recommend setting up VSCode Arduino plugin.  If you open this directory with VSCode, it is already set up so all you need to do is
run Arduino: Verify from the command pallet (You will still need to install Arduino, Bounce Library and add the LUFA board manager URL before you can run verify).
The .hex file will be created in the Build folder.

Take the .hex file and use [QMK Toolbox](https://github.com/qmk/qmk_toolbox) to flash the .hex file.

In QMK Toolbox, Press OPEN and select the .hex file you just created, (or just use the one in the repository).  Select ATMega32U4 from the dropdown menu at the top right corner.
Click the Reset button on the Pro-Micro (Double-Click on Qwiik ProMicro USB-C variant).  When you see the "Caterina device connected (usbser): ~~~" text, press Flash button.

This method, while requires extra software setups, is more reliable than trying to time the Reset while Arduino IDE is doing it's thing...

## Pinout

Configurable in the .ino

The key config is already setup to match Flatbox-ACR wiring.

```C
/* PINOUT (follows Nintendo naming (X=up, B=down)) */
#define PIN_UP    9
#define PIN_DOWN  7
#define PIN_LEFT  6
#define PIN_RIGHT 8
#define PIN_A     MISO         //XBOX B
#define PIN_B     10           //XBOX A  
#define PIN_X     15           //XBOX Y
#define PIN_Y     MOSI         //XBOX X     
#define PIN_L     21           //XBOX LB
#define PIN_R     19           //XBOX RB
#define PIN_ZL    20           //XBOX LT
#define PIN_ZR    18           //XBOX RT
#define PIN_LS    5            //XBOX LS (left analog click)
#define PIN_RS    3            //XBOX RS (right analog click)
#define PIN_PLUS  1            //XBOX START
#define PIN_MINUS 2            //XBOX BACK
#define PIN_HOME  0
```

## Donation

If this project helped you, please consider going to the original works and donate to the source work ;)

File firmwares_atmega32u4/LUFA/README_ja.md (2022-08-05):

## LUFA Switch/XInput ハイブリッドアケコンファームウェア

このファームウェアは[CrazyRedMachine](https://github.com/CrazyRedMachine)様による
[LUFAHybridFightstick](https://github.com/CrazyRedMachine/LUFAHybridFightstick)のFlatbox ACR向け改造版になります。

## 謝辞 

このファームは[CrazyRedMachine](https://github.com/CrazyRedMachine)様による
[LUFAHybridFightstick](https://github.com/CrazyRedMachine/LUFAHybridFightstick)のフォークで、
[fluffymadness' ATMega32U4-Switch-Fightstick](https://github.com/fluffymadness/ATMega32U4-Switch-Fightstick)
と [bootsector's XInputPadMicro](https://github.com/bootsector/XInputPadMicro)をベースに作成されています。

このフォークではFlatbox ACRに対応するため、以下の修正を入れています。

* Flatbox ACR の配線に合わせたキーマップの修正
* アナログスティック対応コードの削除
* 設定関連（SOCDクリーナー設定等）のボタンを他のFlatbox ACRと合わせるためマッピング変更
    * SOCDクリーナー設定は起動時のみに変更し、プリセットの選択のみとしました
      （全ニュートラル、Hitbox風、ガフロコン風）
    * 追加で上下キーの反転機能を追加。格ゲー以外のゲームでの利用向け。

## 機能

### ゲームパッドモード設定

起動時（USB接続時もしくはリセットボタン短押し時）に ”Select” を押したまま起動することで
ニンテンドースイッチコントローラーとして動作します。

起動時（USB接続時もしくはリセットボタン短押し時）に ”Start” を押したまま起動することで
XInputコントローラーとして動作します。

ゲームパッドモードは保持されるため、コントローラーの切断時でも保持されます。起動時に何も押さなければ
以前設定したモードで動作します。

### 方向キー設定

方向キーのモードは動作中に動的に切り替えが可能です。START+SELECT+(←／↑／→) のキーコンボで設定できます。

* ↑： 十字キーとして動作
* ←： 疑似左アナログスティックとして動作（十字キーを左アナログスティックとしてマッピング）
* →： 疑似右アナログスティックとして動作（十字キーを右アナログスティックとしてマッピング）

方向キーモード設定も電源オフでも保持されます。

以下にある上限反転をしている場合は上下反転された状態での↑を利用してください。

### アナログ入力サポート機能

Flatbox ACRにはアナログ入力がないため機能削除しました。

### ホームボタンシミュレート機能

Flatbox ACRにはHomeボタンがあるため機能削除しました。

### SOCD クリーナー設定

* 起動時にHOME(PS)押下＝全ニュートラル
* 起動時にR3(RS)押下＝ヒットボックス風SOCDクリーナー（↑＋↓＝↑、←＋→＝ニュートラル）
    * 一部公式大会等でも許可されたモードです（大会毎にルールが違う可能性があるためルール確認のこと）
* 起動時にL3(LS)押下＝ガフロコン風SOCDクリーナー（↑＋↓＝↑、←＋→＝後勝ち）
    * 一部公式大会等では禁止されているモードです。

起動時設定なので、USB接続時か、リセットボタンを使うことで設定可能です。

### 上下入力反転設定

Flatbox ACRはHitbox風コントローラーのため、上下キーのレイアウトが少々変わっているため、格ゲー以外では
利用しづらい為、格ゲー以外で利用するときのために上下反転する機能を追加しました。

* 起動時に上ボタン（十字キーの親指のボタン）を押下＝上下反転
* 起動時に下ボタン（十字キーの真ん中のボタン）を押下＝反転解除

## ファームウェアビルド手順

1. [Arduino IDE](https://www.arduino.cc/en/software)をダウンロードしてインストールしてください。
2. Arduino IDE内のライブラリ管理メニューからBounce2ライブラリをインストールしてください。
3. ファイル→環境設定から追加のボードマネージャURLに
   `https://github.com/CrazyRedMachine/Arduino-Lufa/raw/master/package_arduino-lufa_index.json` を追加。
4. ツール→ボード→ボードマネージャからLUFA AVR Boardをインストール
5. ツール→ボード以下で Arduino Leonardo (LUFA) を選択
    * Pro-MicroはArduino Leonardoの互換ボードなのでこちらで動作します
6. マイコンボードに書き込みで書き込み出来ます。
    * 初回の書き込みは特に何もしなくても上記設定をして付属の.inoを書き込めば書き込めますが2度め以降は
      書き込み出来ません。これはHIDモードで動作するファームはArduino IDEからのリセット要求に対応できない
      ためです。2回め以降の書き込みを行う場合は Arduino IDE で書き込みボタンを押してからログで
      PORTS {} / {} => {} といったような内容が出力され始めた段階でリセットボタンを押下（Pro-Micro Qwiic
      の場合はリセットボタンをダブルクリック）することで書き込みが出来ます。
    * 上記ログを表示するためには Arduino IDE の環境設定で「より詳細な情報を表示する」にチェックを入れると
      出ます
    * タイミングが難しい場合は以下に記載している .hex ファイルを取り出して QMK Toolbox で書き込みする方法も
      あります。

### ファームの書き込み方法

USB HID対応のファームをAVRボードに書き込みすると、Arduino IDEから書き込み時の自動リセットを受け付けなくなります。
一度ファームを書き込んだ後は書き込み処理時に手動でリセット（Flatbox ACRではSW_RST1）を押す必要があります。
Sparkfun Qwiic Pro Micro 5Vを使った場合はリセットをダブルクリックすることで書き込みモードに入れることが出来ます。

Arduino IDEでは自分で書き込みのタイミングを制御出来ないため、2回目以降はVSCodeのArduinoプラグインを使って
コンパイルだけ行い、.hex ファイルを取り出して [QMK Toolbox](https://github.com/qmk/qmk_toolbox)を利用して
書き込む方法がおすすめです。
VSCodeは[こちら](https://azure.microsoft.com/ja-jp/products/visual-studio-code/)からダウンロードできます。
インストールが終わったらプラグインからArduinoを検索しマイクロソフト製のArduinoプラグインをインストール。
Arduino IDEで上記の設定が一通り終わった後にこのフォルダをVSCodeで開くことでVSCodeからのコンパイルが可能です。
.inoファイルを開いてVSCodeのコマンドパレットから Arduino: Verify を選択するとコンパイルされ、buildフォルダに
.hexファイルが生成されます。

.hexファイルは[QMK Toolbox](https://github.com/qmk/qmk_toolbox)を使って書き込みが出来ます

1. QMK Toolboxを起動したら、右上のOPENから上記で作成した.hexファイルを選択してください。
2. 右上のドロップダウンから ATMega32u4を選択してください
3. Pro Micro のリセットボタンを押し（Qwiic Pro Micro USB-Cの場合はリセットをダブルクリックし）、QMK Toolbox
   のログ上に黄色の文字で"Caterina device connected (usbser): ~~~"と出たら右上のFlashボタンを押下すると
   書き込みが開始されます。書き込み完了後に自動でボードがリセットされ新しいファームで立ち上がります。

こちらの方法は追加のソフトのセットアップが必要ですが、コンパイルと書き込みを分けて行えるため、リセットのタイミング
が図りやすいため失敗し辛い為おすすめです（ただし初回書き込みはArduino IDEでないとうまくいかない事があったため、
新品のPro Microを書き込む場合はArduino IDEで行う事をおすすめします）

## ピン配置

.ino ファイルで設定可能です。

こちらのリポジトリ内のファイルではすでに Flatbox ACR 向けに設定済みです。

```C
/* PINOUT (follows Nintendo naming (X=up, B=down)) */
#define PIN_UP    9
#define PIN_DOWN  7
#define PIN_LEFT  6
#define PIN_RIGHT 8
#define PIN_A     MISO         //XBOX B
#define PIN_B     10           //XBOX A  
#define PIN_X     15           //XBOX Y
#define PIN_Y     MOSI         //XBOX X     
#define PIN_L     21           //XBOX LB
#define PIN_R     19           //XBOX RB
#define PIN_ZL    20           //XBOX LT
#define PIN_ZR    18           //XBOX RT
#define PIN_LS    5            //XBOX LS (left analog click)
#define PIN_RS    3            //XBOX RS (right analog click)
#define PIN_PLUS  1            //XBOX START
#define PIN_MINUS 2            //XBOX BACK
#define PIN_HOME  0
```

## 寄付

もしこのプロジェクトが参考担った場合はベースとなったプロジェクトにいって寄付すると大本のプロジェクトの
人たちが喜びます。

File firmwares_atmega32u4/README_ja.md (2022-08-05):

# ATMEGA32U4 マイコン用ファームウェア

現在 ATMEGA32U4マイコン製 AVRボード（5Vバージョン）用のファームウェアは２種類あります（3.3V版は非対応）。
どちらのファームもSOCDクリーナーや上下ボタン反転機能は同様に動きます。

以下対応機能表になります。

Firmware            | [DINPUT](DINPUT)      | [LUFA](LUFA)          |
------------------- | :-------------------: | :-------------------: |
DInput              | **YES**               | NO                    |
XInput              | NO                    | **YES**               |
PS3                 | **YES**               | NO                    |
Switch              | NO                    | **YES**               |
SOCD                | Hitbox,Gafro,NEUTRAL  | Hitbox,Gafro,NEUTRAL  |
Vertical Inversion  | **YES**               | **YES**               |
DPAD emulation      | **YES**               | **YES**               |
Fake Left Stick     | NO                    | **YES**               |
Fake Right Stick    | NO                    | **YES**               |

## 各種設定 

以下の表に各ファームウェアが対応する設定機能と操作方法を示します。
設定はすべて電源オフしても保持されます。

| ファーム | | DINPUT | LUFA |
| :--- | :---: | :---: | :---: |
| 上下反転 | 標準 | ↓ + リセット | ↓ + リセット |
| | 上下反転 | ↑ + リセット | ↑ + リセット |
| SOCDクリーナー | Hitboxモード | R3(RS) + リセット | R3(RS) + リセット |
| | ガフロコンモード | L3(LS) + リセット | L3(LS) + リセット |
| | 全ニュートラル | PS(HOME) + リセット | PS(HOME) + リセット |
| 入力モード変更 | Xinput | 非対応 | "Start" + リセット |
| | Switch | 非対応 | "Select" + リセット |
| | DInput/PS3 | デフォルト | 非対応 |
| 方向入力モード | 十字キー | デフォルト | UP+START+SELECT |
| | 左アナログスティック  | 非対応 | LEFT+START+SELECT |
| | 右アナログスティック  | 非対応 | RIGHT+START+SELECT |

リセットキーを使った設定は対応したキーを押したままリセットキーを一回短押しして、コントローラーが
再接続するまで待ってください。接続完了時に押されていたキーを判定して設定変更が行われるので、対応キーを
離すのが早すぎると設定されない場合があります。

キーコンボの[カンニングペーパー](Flatbox-ACR_Hotkey_Cheatsheet.pdf)を作ったので覚えるのが面倒な場合は
こちらを印刷して裏側等に挟み込んでご利用ください（印刷サイズ：B5）

## [DINPUT](./DINPUT/)

こちらのファームはオリジナルのFlatboxのファーム(Dinput)をベースにしたものになります。
シンプルなファームでPS3まで対応しているためPC(DInput)とPS3を利用する場合はこちらをご利用ください。

## [LUFA](./LUFA/)

こちらは[CrazyRedMachine](https://github.com/CrazyRedMachine)様作成の
[LUFAHybridFightstick](https://github.com/CrazyRedMachine/LUFAHybridFightstick)をベースにFlatbox ACR用にカスタマイズ
したファームになります。Xinputとニンテンドースイッチに対応しています（XinputはPCのみ対応。XBoxには認証チップ
が必要なため非対応になります）。

スイッチモードとXInputモードはキーコンボで設定切り替え可能です（上記表参照）。
また、疑似アナログスティック入力に対応しています。

PCで利用する際にDInput非対応のソフトを利用する場合やニンテンドースイッチで利用する場合にこちらをお使いください。

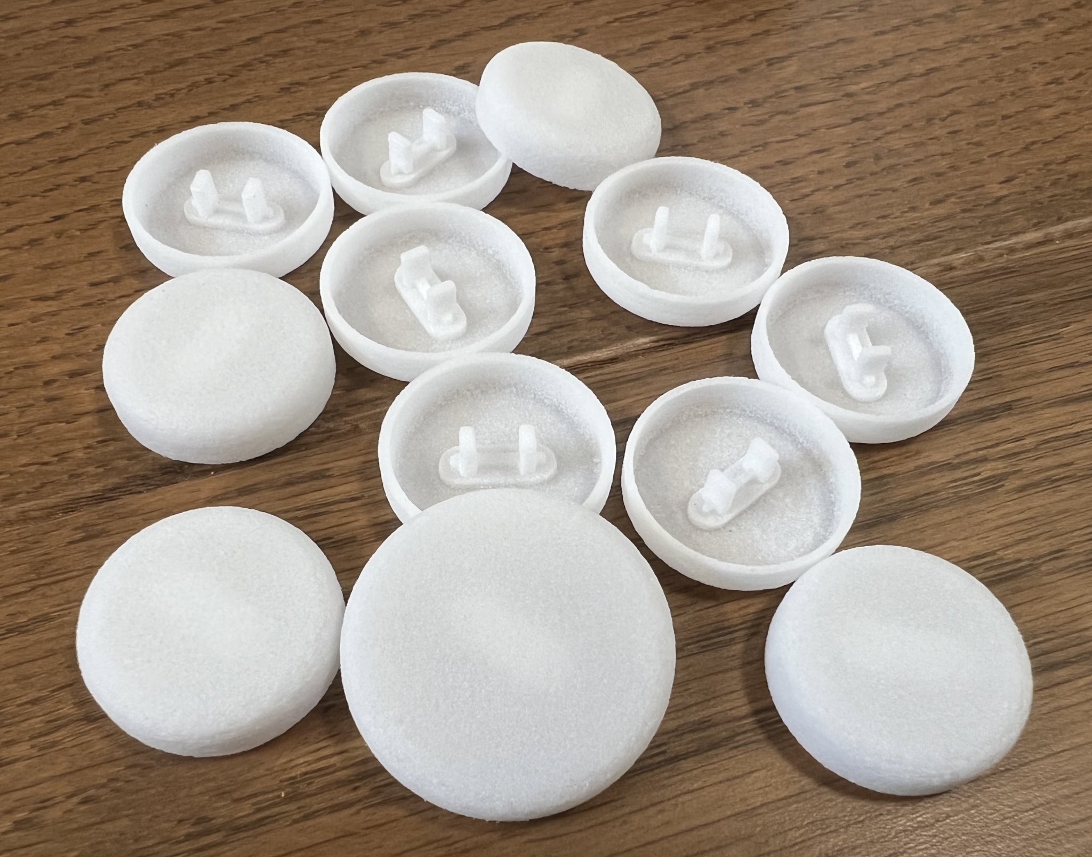
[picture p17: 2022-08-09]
hardware-rev1.1/images/Flatbox-rev1.1-button-cap-rev1.jpg

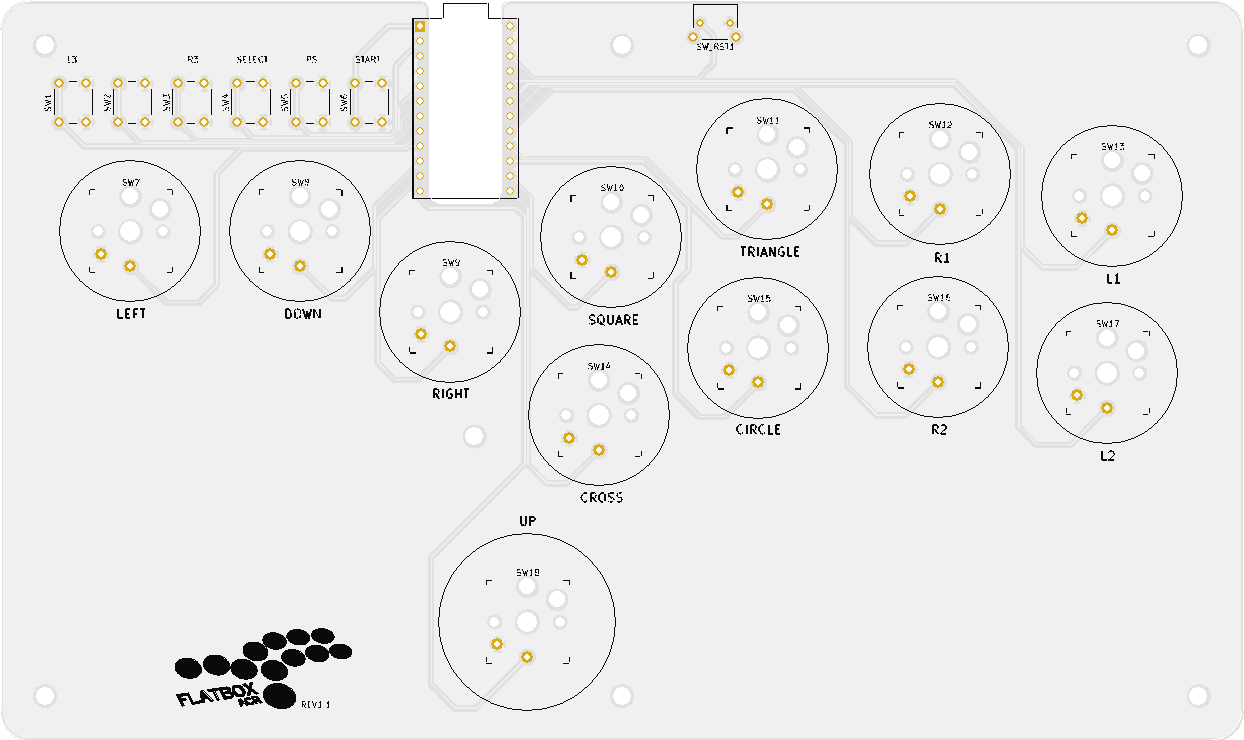
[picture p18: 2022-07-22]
hardware-rev1.1/images/Flatbox-rev1.1-pcb.jpg

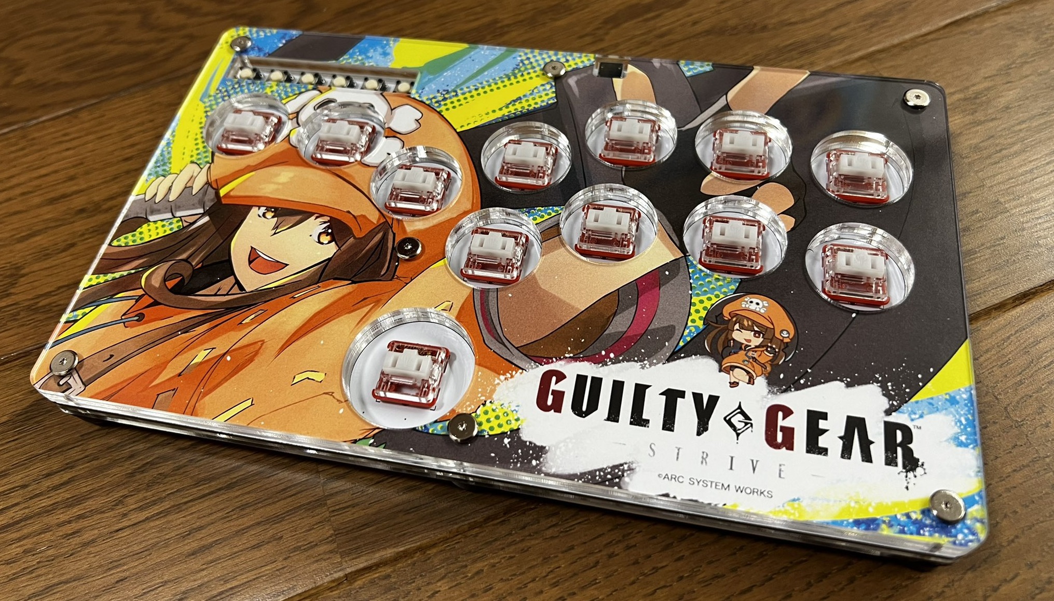
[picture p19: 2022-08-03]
hardware-rev1.1/images/Flatbox-rev1.1-withFanArt.jpg

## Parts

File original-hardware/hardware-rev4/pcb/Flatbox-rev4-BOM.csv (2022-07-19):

Comment | Designator | Footprint | LCSC
30p | C2,C3 | Capacitor_SMD:C_0402_1005Metric | C1570
1u | C1,C4,C8,C10 | Capacitor_SMD:C_0402_1005Metric | C52923
100n | C5,C6,C7,C9,C11,C12,C13,C14,C15,C16 | Capacitor_SMD:C_0402_1005Metric | C1525
10k | R2 | Resistor_SMD:R_0402_1005Metric | C25744
27 | R3,R4 | Resistor_SMD:R_0402_1005Metric | C138021
1k | R1,R5 | Resistor_SMD:R_0402_1005Metric | C11702
5.1k | R6,R7 | Resistor_SMD:R_0402_1005Metric | C25905
SW_Push | SW1,SW2,SW3,SW4,SW5,SW6 | Button_Switch_THT:SW_PUSH_6mm_H5mm
SW_Push | SW19,SW20 | Button_Switch_SMD:SW_SPST_Omron_B3FS-100xP | C271750
SW_Push | SW7,SW8,SW9,SW10,SW11,SW12,SW13,SW14,SW15,SW16,SW17,SW18 | Kailh:Kailh_socket_PG1350_optional
TLV73333PDBV | U1 | Package_TO_SOT_SMD:SOT-23-5 | C134139
W25Q128JVS | U2 | Package_SO:SOIC-8_5.23x5.23mm_P1.27mm | C97521
RP2040 | U3 | RP2040:RP2040-QFN-56 | C2040
HRO-TYPE-C-31-M-12 | USB1 | Type-C:HRO-TYPE-C-31-M-12-Assembly | C165948
Crystal_GND24 | Y1 | Crystal:Crystal_SMD_3225-4Pin_3.2x2.5mm | C9002

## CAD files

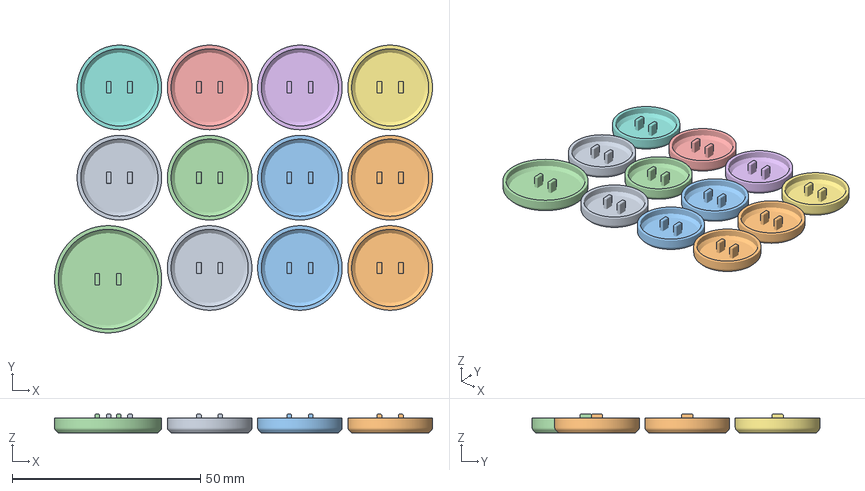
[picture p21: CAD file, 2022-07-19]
original-hardware/3d-printed-buttoncaps/FullSetButtonCaps.FCStd
100.5 x 76.5 x 5.00 mm
Buttoncap
Buttoncap001
Buttoncap002
Buttoncap003
Buttoncap004
Buttoncap005
Buttoncap006
Buttoncap007
Buttoncap008
Buttoncap009
Buttoncap010
ButtoncapBig

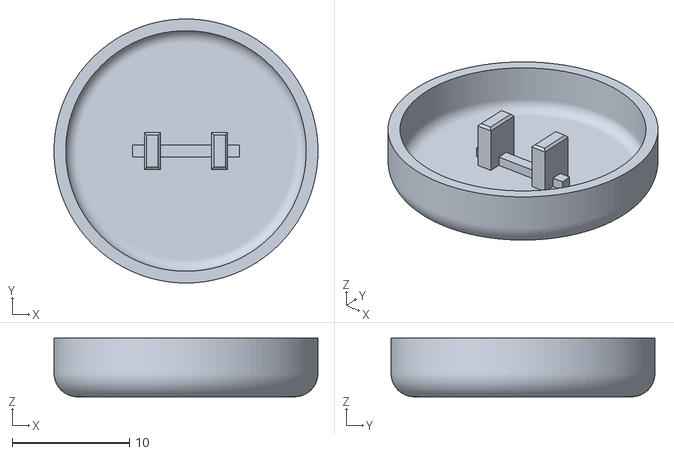
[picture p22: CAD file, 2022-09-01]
3d-printed-buttoncaps/Flatbox-ACR-ButtonCap_rev1.1.stl
22.5 x 22.5 x 5.00

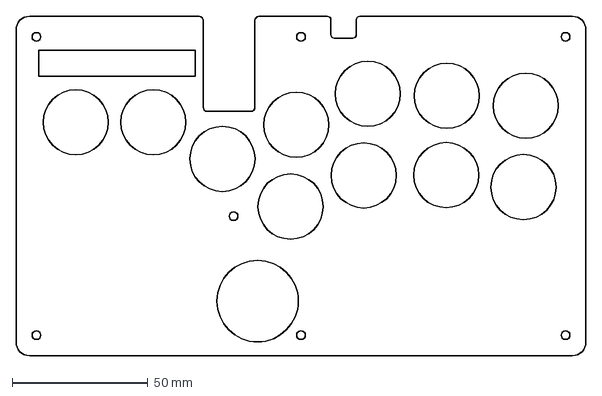
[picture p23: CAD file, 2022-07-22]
hardware-rev1.1/acrylic-shell/acryl-design-Flatbox-ACR-Acrylic-layer-02.dxf
210.0 x 125.0 mm

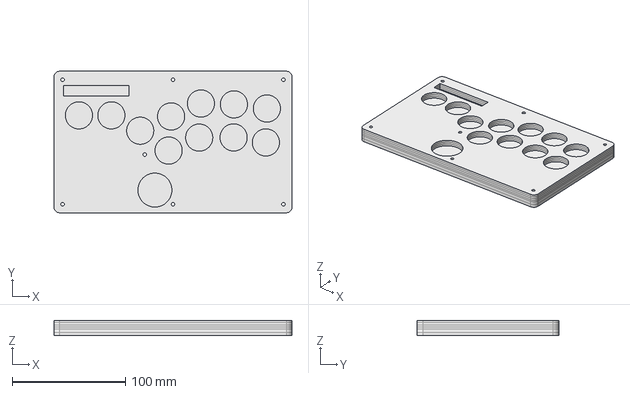
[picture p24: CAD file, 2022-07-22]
hardware-rev1.1/design_data/acryl-design/acryl-design.FCStd
210.0 x 125.0 x 13.6 mm

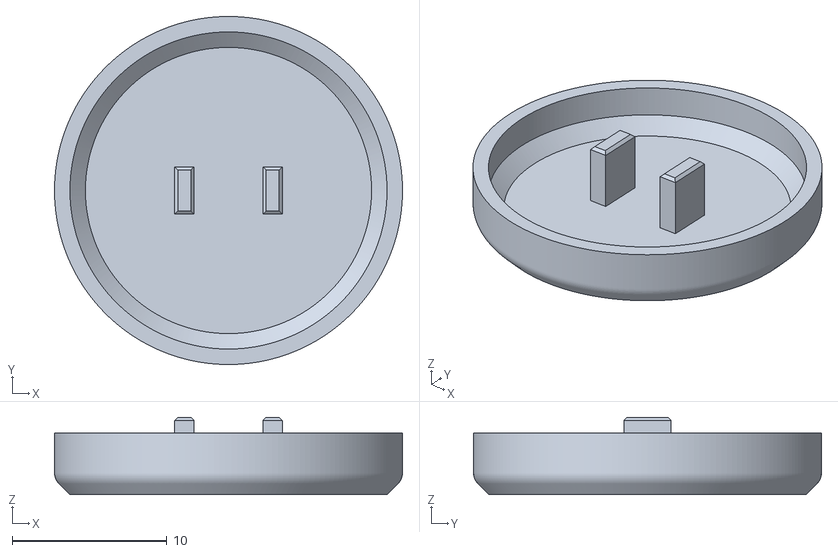
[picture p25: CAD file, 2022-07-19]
original-hardware/3d-printed-buttoncaps/Buttoncap.stl
22.5 x 22.5 x 5.00

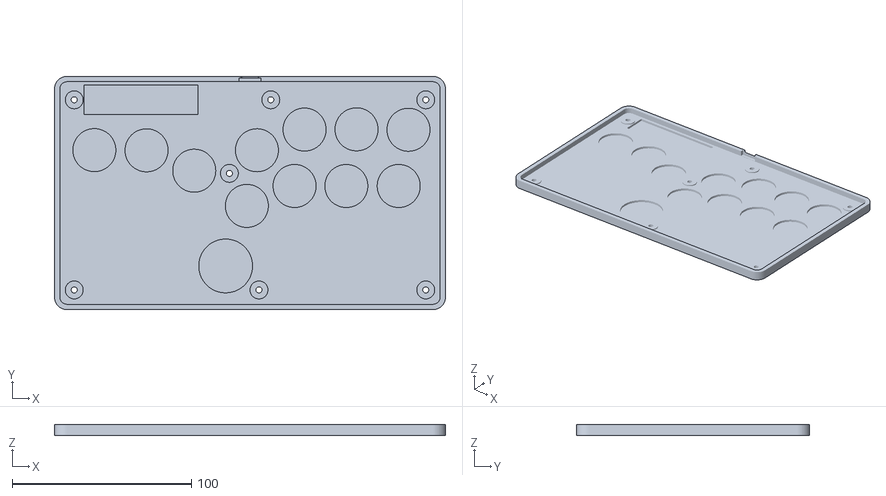
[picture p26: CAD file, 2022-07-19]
original-hardware/hardware-rev4/3d-printed-case/Flatbox-rev4-Bottom-hotswap.stl
218.0 x 130.1 x 6.20

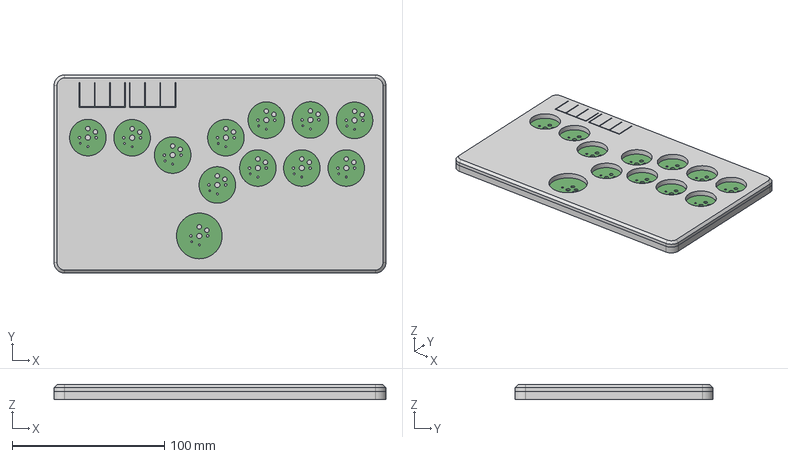
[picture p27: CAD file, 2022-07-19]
original-hardware/hardware-rev4/extras/Flatbox-rev4-case.step
218.0 x 130.1 x 9.80 mm

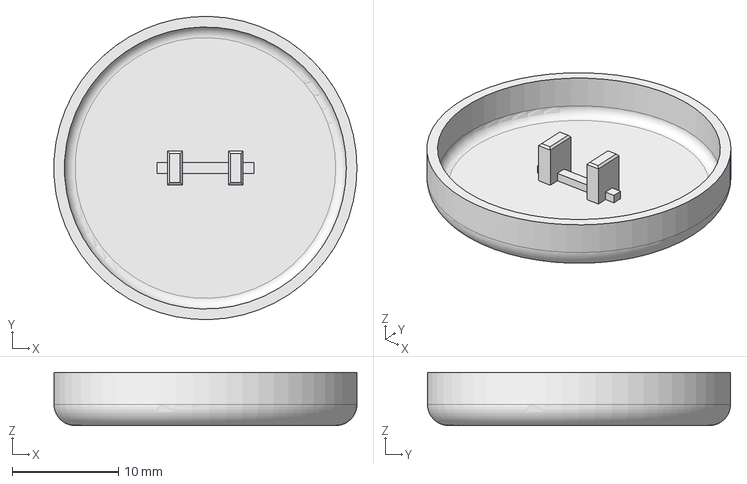
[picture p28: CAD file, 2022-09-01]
3d-printed-buttoncaps/Flatbox-ACR-ButtonCapBig.FCStd
28.5 x 28.5 x 5.00 mm

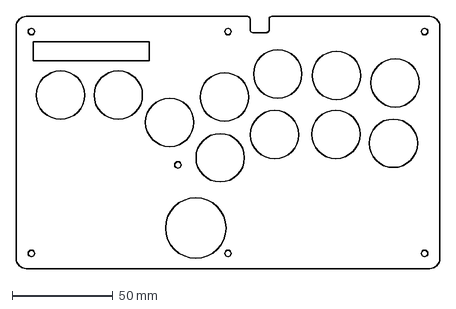
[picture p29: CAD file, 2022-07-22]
hardware-rev1.1/acrylic-shell/acryl-design-Flatbox-ACR-Acrylic-layer-04.dxf
210.0 x 125.0 mm

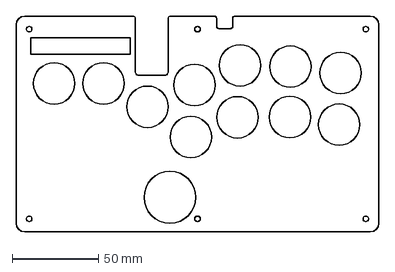
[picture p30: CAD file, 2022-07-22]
Hitbox Layout/hblayout-Shape2DView.dxf
210.0 x 125.0 mm

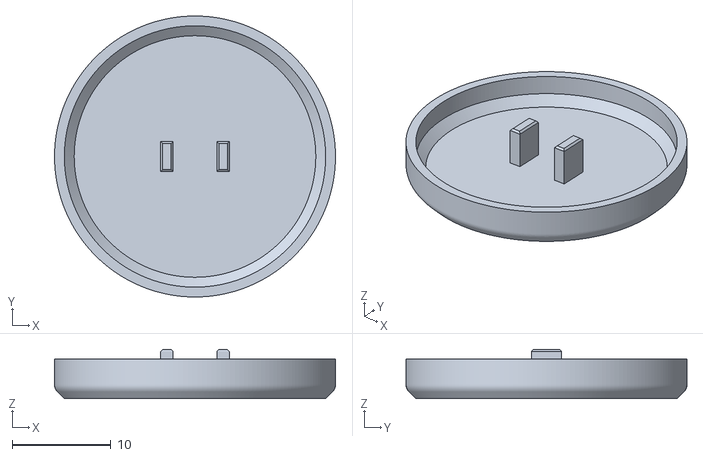
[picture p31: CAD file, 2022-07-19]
original-hardware/3d-printed-buttoncaps/ButtoncapBig.stl
28.5 x 28.5 x 5.00

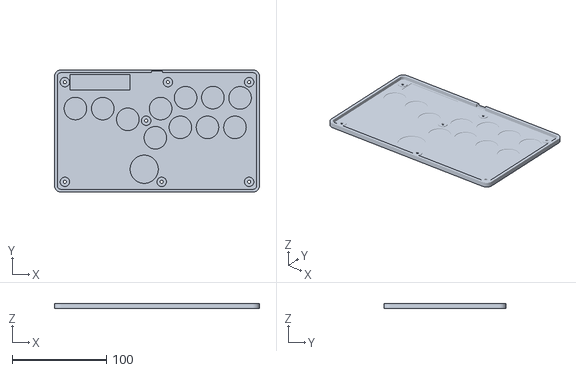
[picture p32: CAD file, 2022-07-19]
original-hardware/hardware-rev4/3d-printed-case/Flatbox-rev4-Bottom.stl
218.0 x 130.1 x 5.20

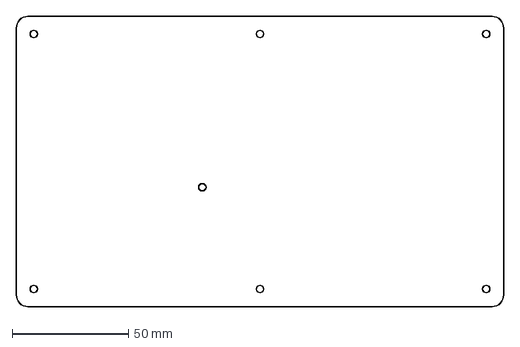
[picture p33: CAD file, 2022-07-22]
hardware-rev1.1/acrylic-shell/acryl-design-Flatbox-ACR-Acrylic-layer-01.dxf
210.0 x 125.0 mm

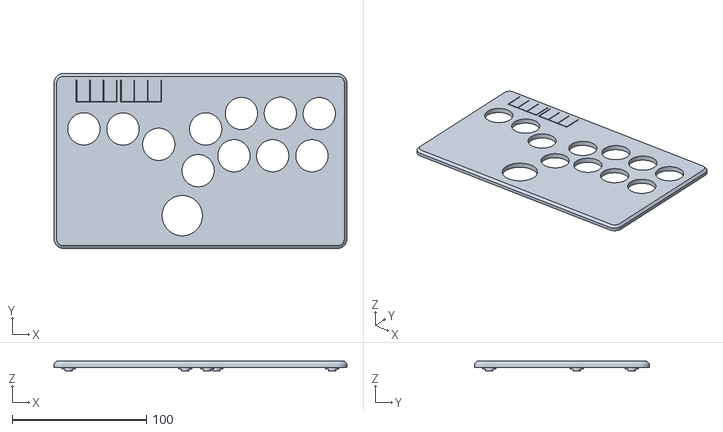
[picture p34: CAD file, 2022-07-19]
original-hardware/hardware-rev4/3d-printed-case/Flatbox-rev4-Top.stl
218.0 x 130.1 x 7.20

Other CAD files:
Hitbox Layout/hblayout.FCStd
3d-printed-buttoncaps/Flatbox-ACR-ButtonCapBig_rev1.1.stl
3d-printed-buttoncaps/Flatbox-ACR-ButtonCap.FCStd
hardware-rev1.1/acrylic-shell/acryl-design-Flatbox-ACR-Acrylic-layer-03.dxf
3d-printed-buttoncaps/Flatbox-ACR-ButtonCap.stl
3d-printed-buttoncaps/Flatbox-ACR-ButtonCapBig.stl
hardware-rev1.1/acrylic-shell/acryl-design-Flatbox-ACR-Acrylic-layer-05.dxf
hardware-rev1/acrylic-shell/acryl-design-Flatbox-ACR-Acrylic-layer-01.dxf
original-hardware/3d-printed-buttoncaps/FullSetButtonCaps.stl
original-hardware/hardware-rev1.1/3d-printed-case/Flatbox-rev1.1-Bottom-hotswap.stl
original-hardware/hardware-rev1.1/3d-printed-case/Flatbox-rev1.1-Bottom.stl
original-hardware/hardware-rev1.1/3d-printed-case/Flatbox-rev1.1-Top.stl
original-hardware/hardware-rev1.1/extras/Flatbox-rev1.1-case.step
original-hardware/hardware-rev1.1/extras/Flatbox-rev1.1-pcb.step
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

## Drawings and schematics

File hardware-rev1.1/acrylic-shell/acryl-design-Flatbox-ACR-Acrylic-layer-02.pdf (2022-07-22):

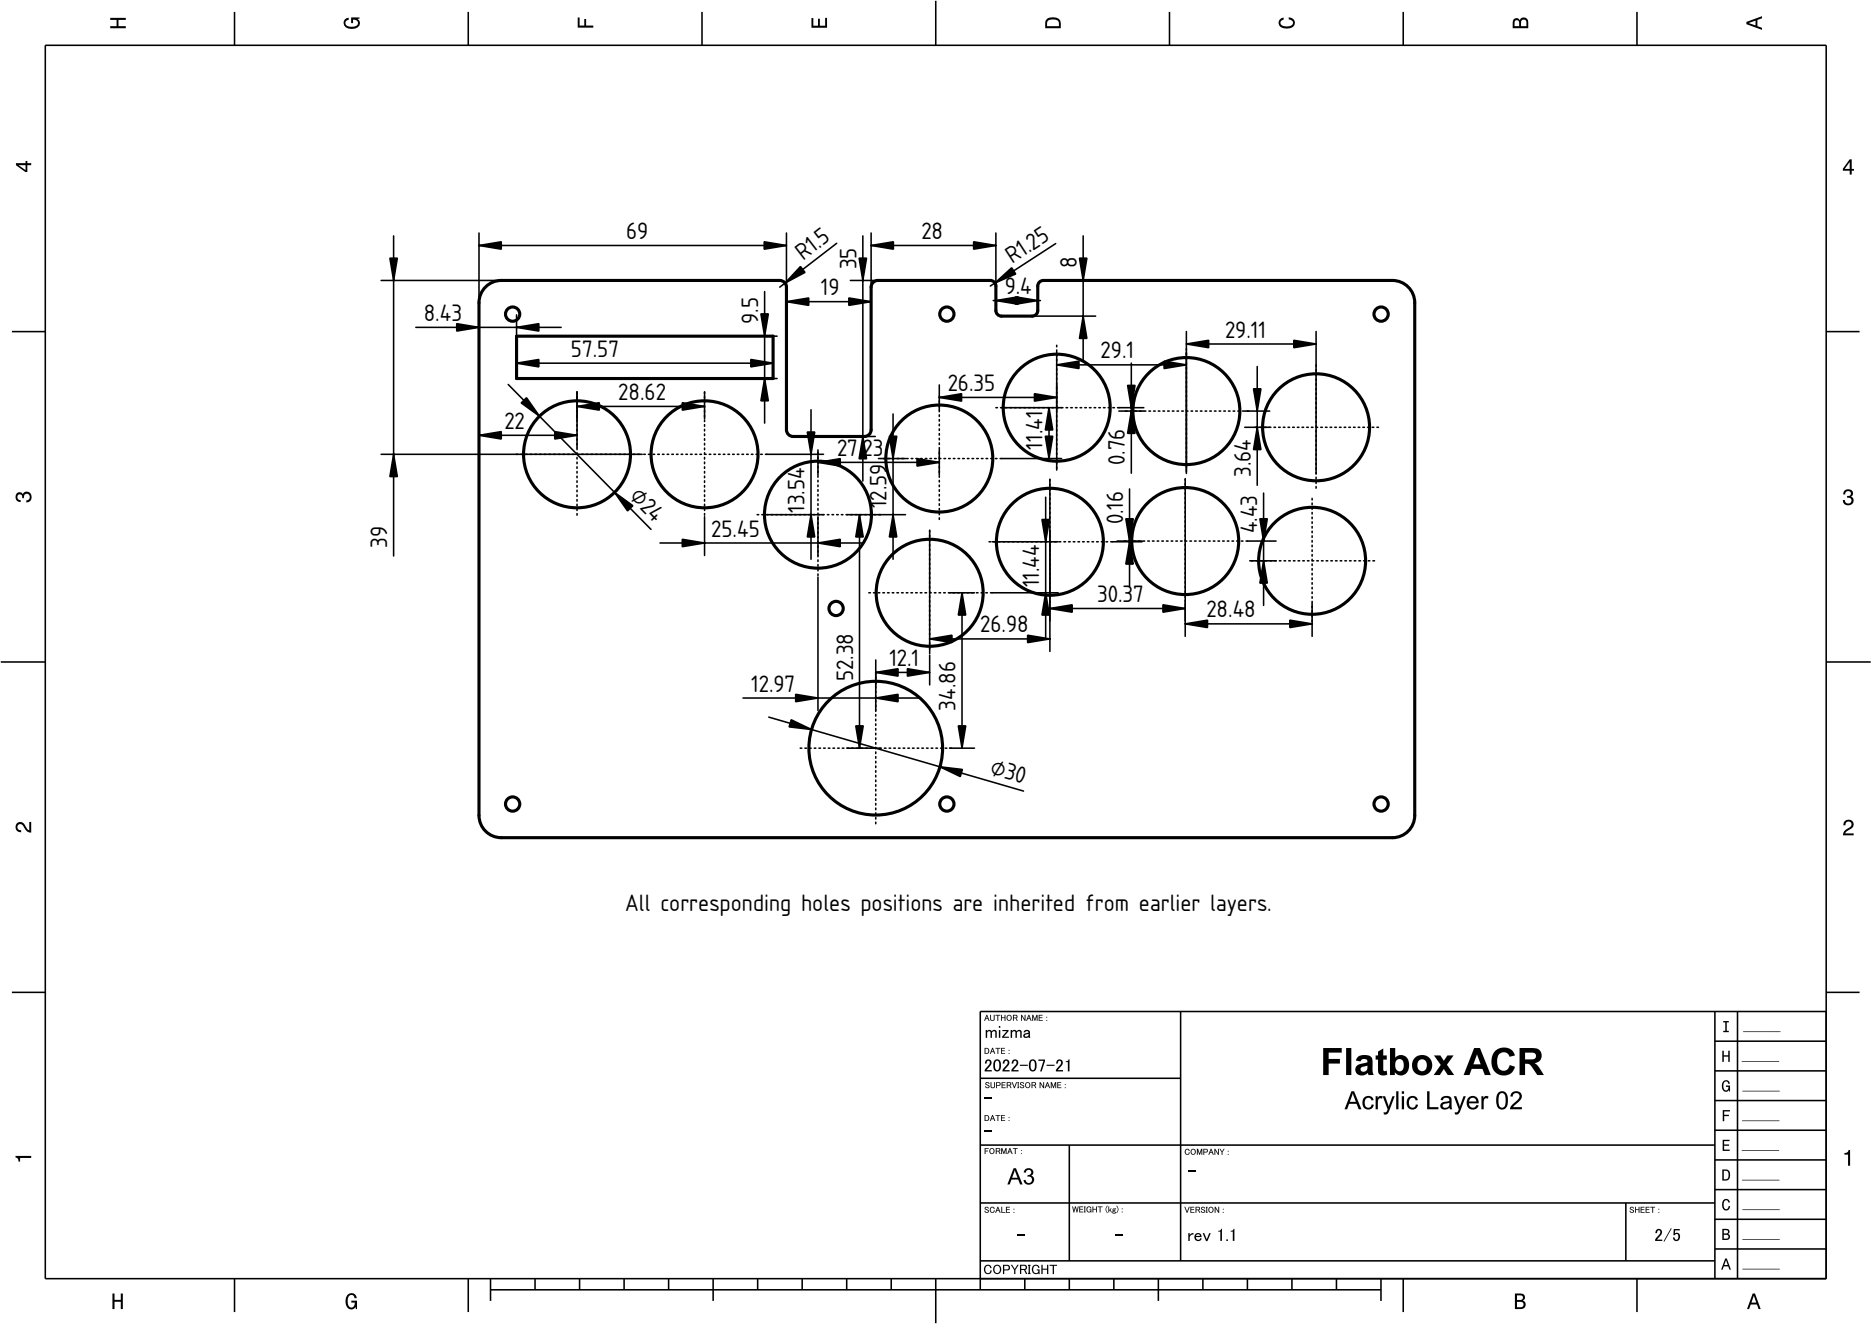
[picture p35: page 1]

All corresponding holes positions are inherited from earlier layers.

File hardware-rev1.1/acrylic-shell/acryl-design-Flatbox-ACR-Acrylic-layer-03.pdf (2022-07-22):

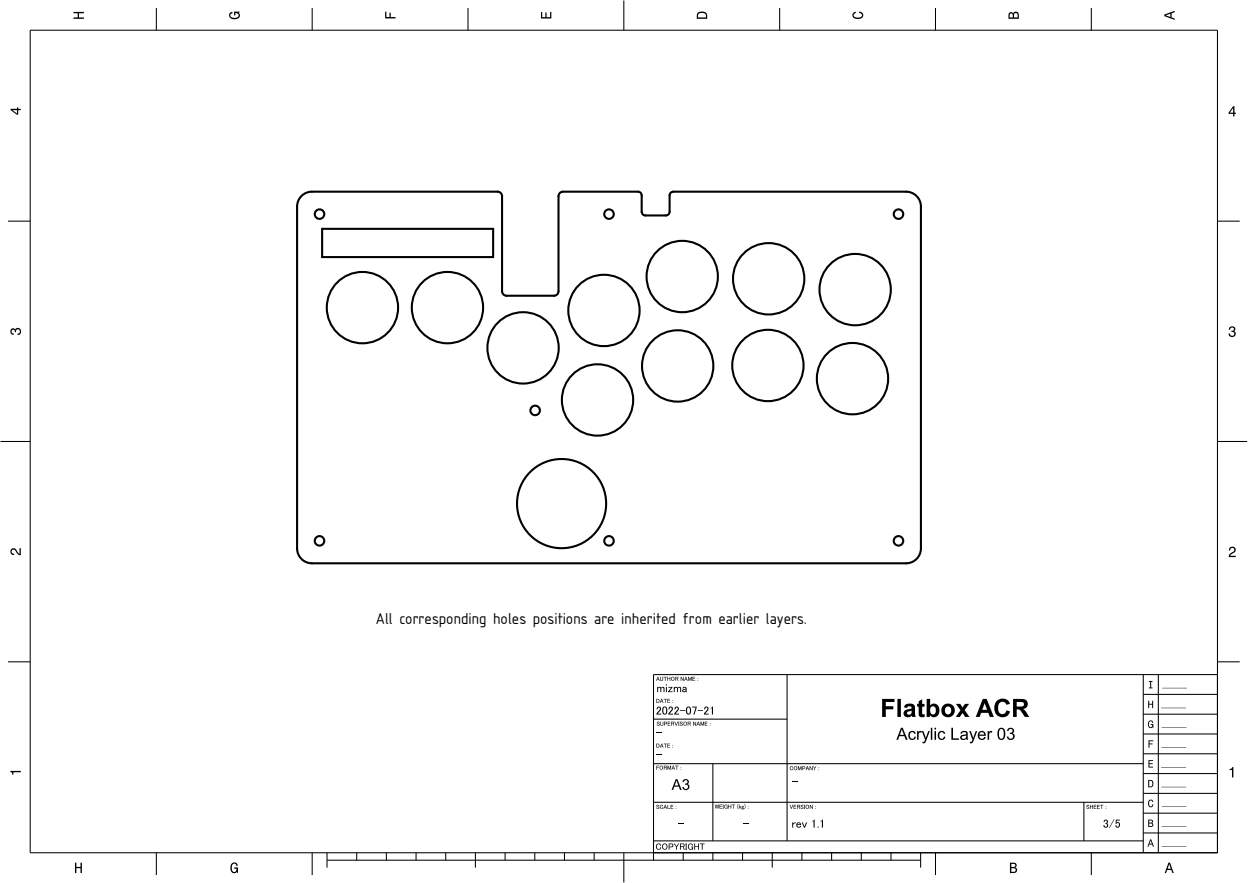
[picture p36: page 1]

All corresponding holes positions are inherited from earlier layers.

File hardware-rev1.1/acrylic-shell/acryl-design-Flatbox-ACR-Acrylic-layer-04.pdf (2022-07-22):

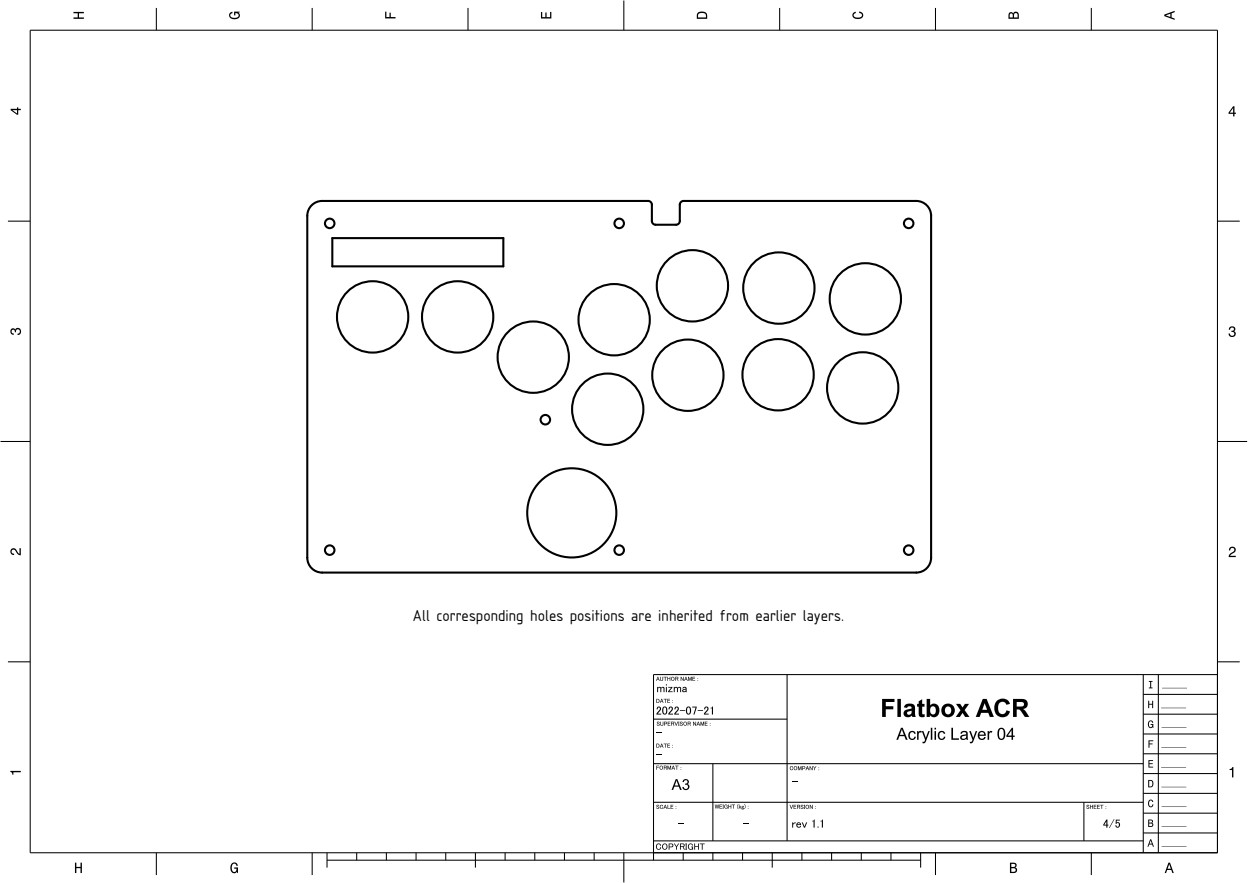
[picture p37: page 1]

All corresponding holes positions are inherited from earlier layers.

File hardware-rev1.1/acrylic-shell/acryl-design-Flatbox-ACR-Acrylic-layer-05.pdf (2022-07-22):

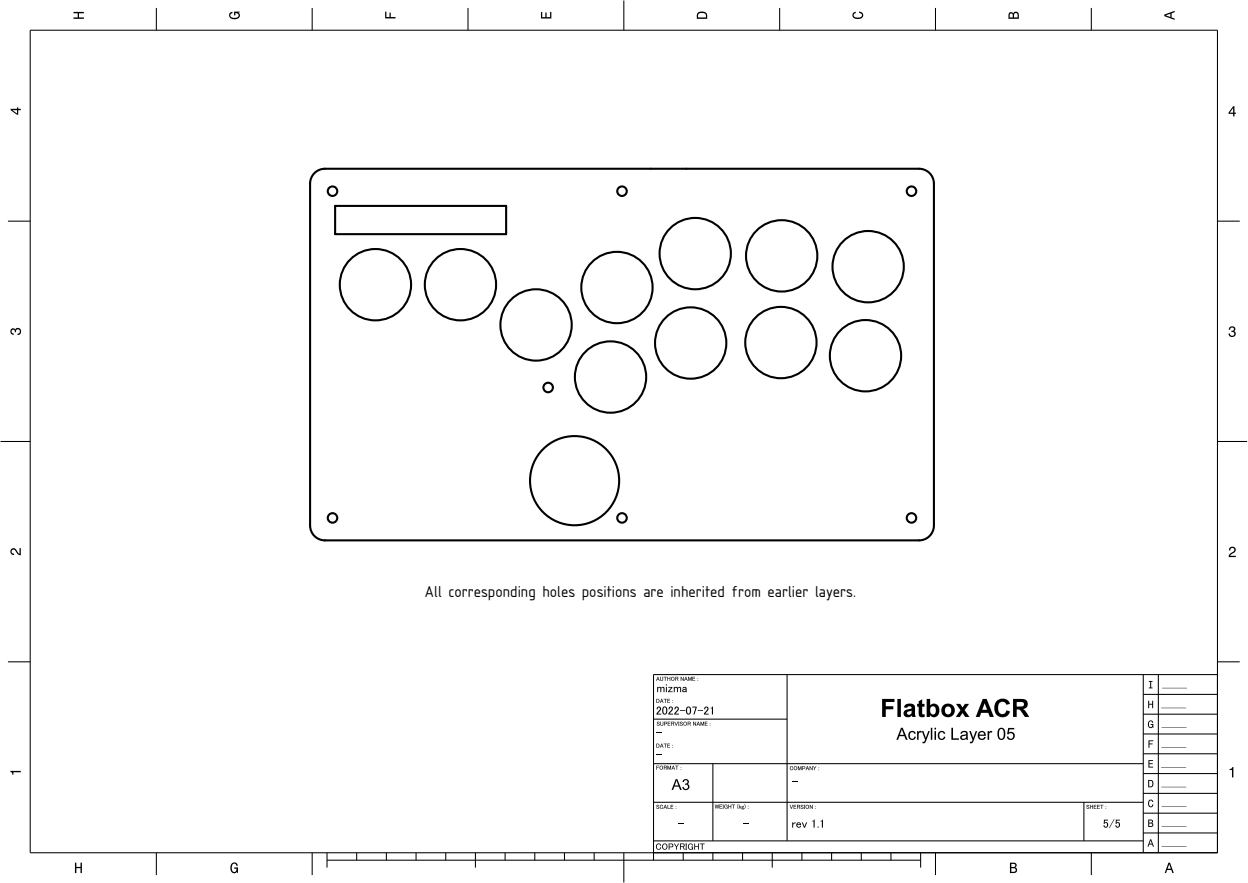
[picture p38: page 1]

All corresponding holes positions are inherited from earlier layers.

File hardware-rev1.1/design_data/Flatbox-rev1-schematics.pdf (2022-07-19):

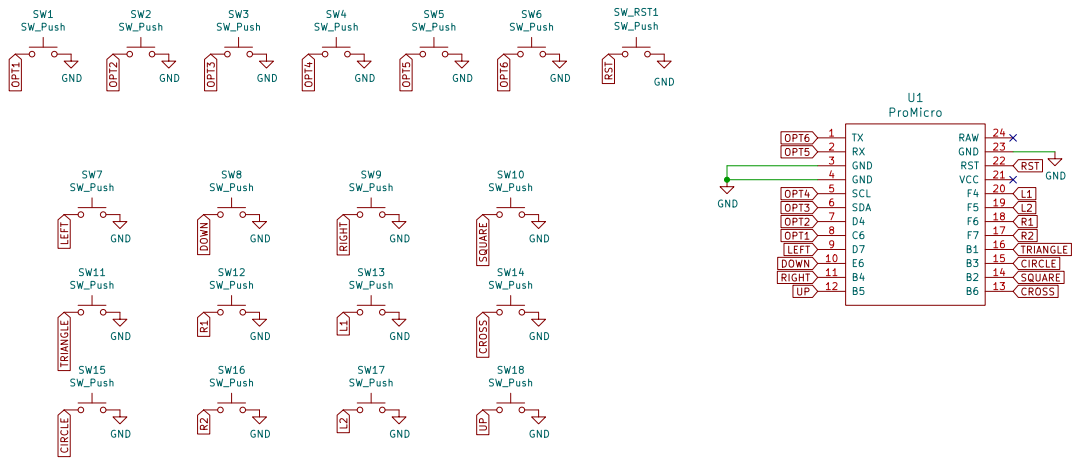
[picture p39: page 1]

File: Flatbox-rev1-kicad.kicad_sch Sheet: /
Id: 1/1 Title: Flatbox ACR rev.1

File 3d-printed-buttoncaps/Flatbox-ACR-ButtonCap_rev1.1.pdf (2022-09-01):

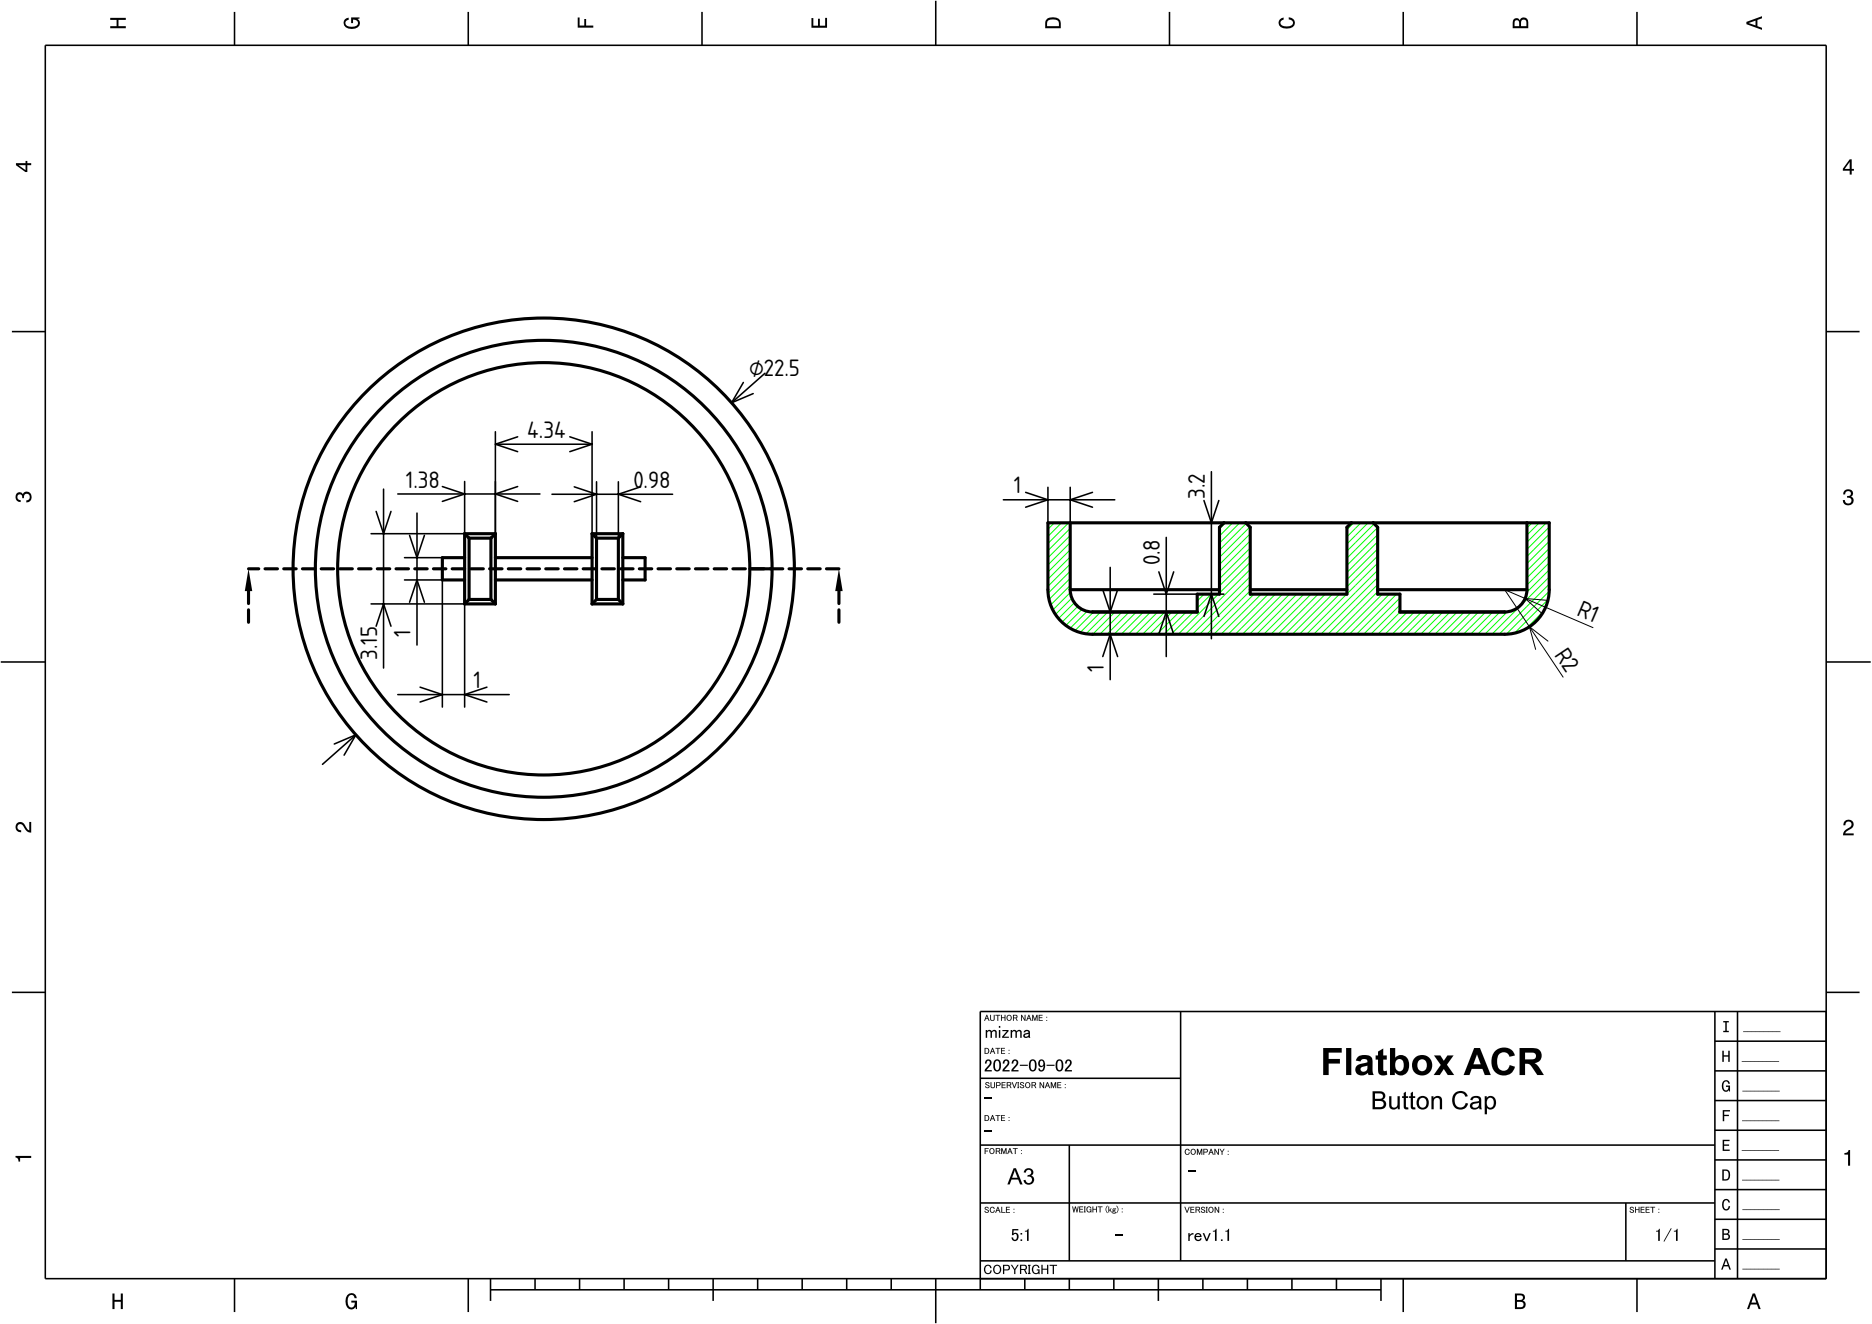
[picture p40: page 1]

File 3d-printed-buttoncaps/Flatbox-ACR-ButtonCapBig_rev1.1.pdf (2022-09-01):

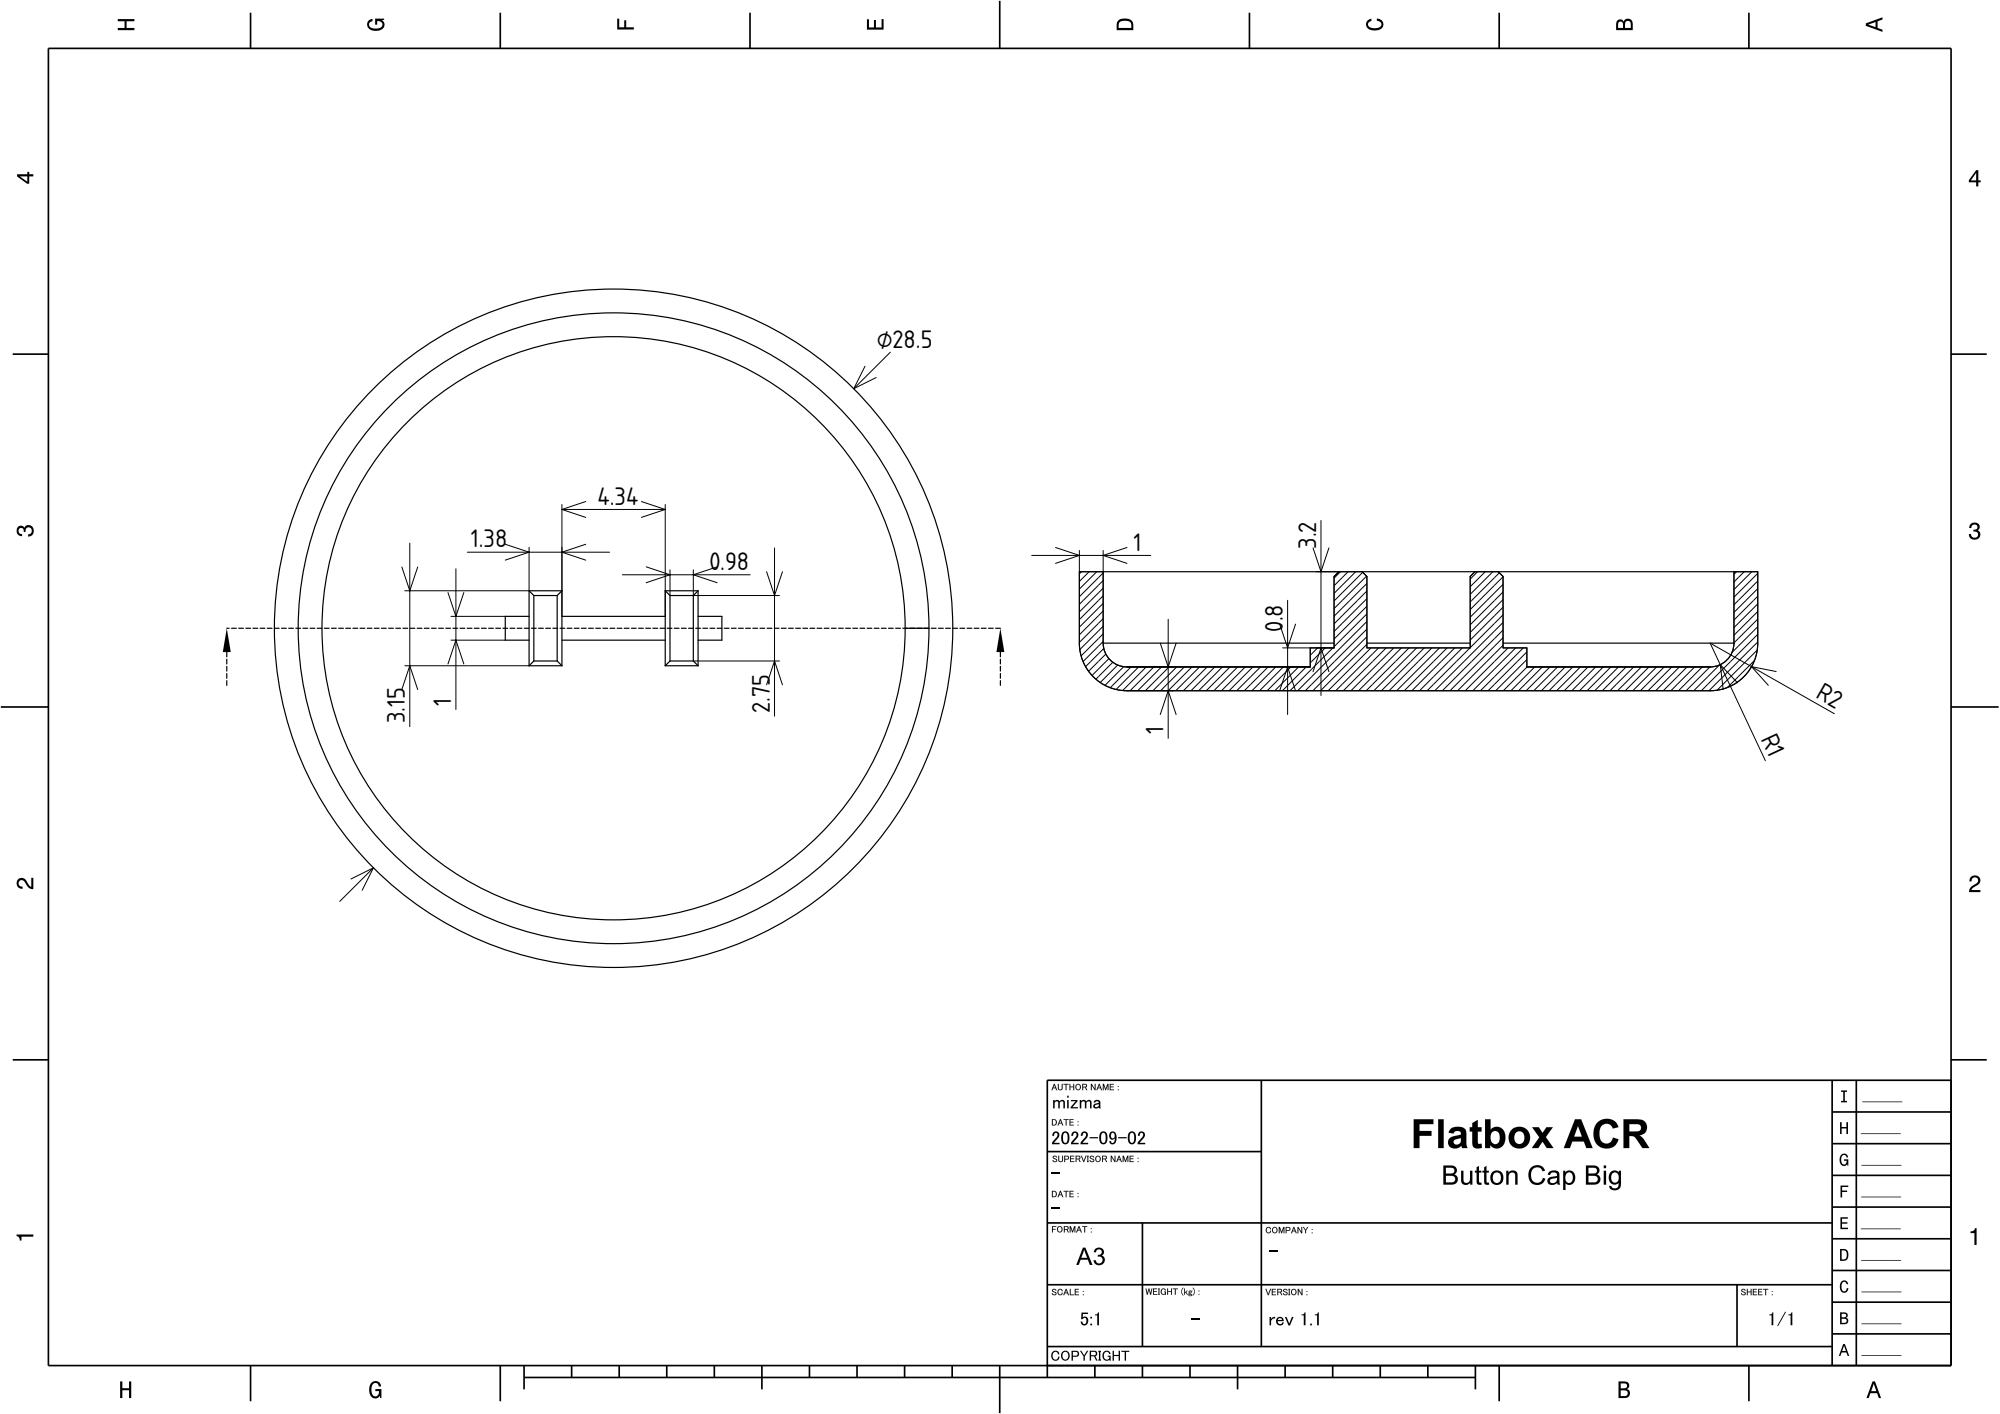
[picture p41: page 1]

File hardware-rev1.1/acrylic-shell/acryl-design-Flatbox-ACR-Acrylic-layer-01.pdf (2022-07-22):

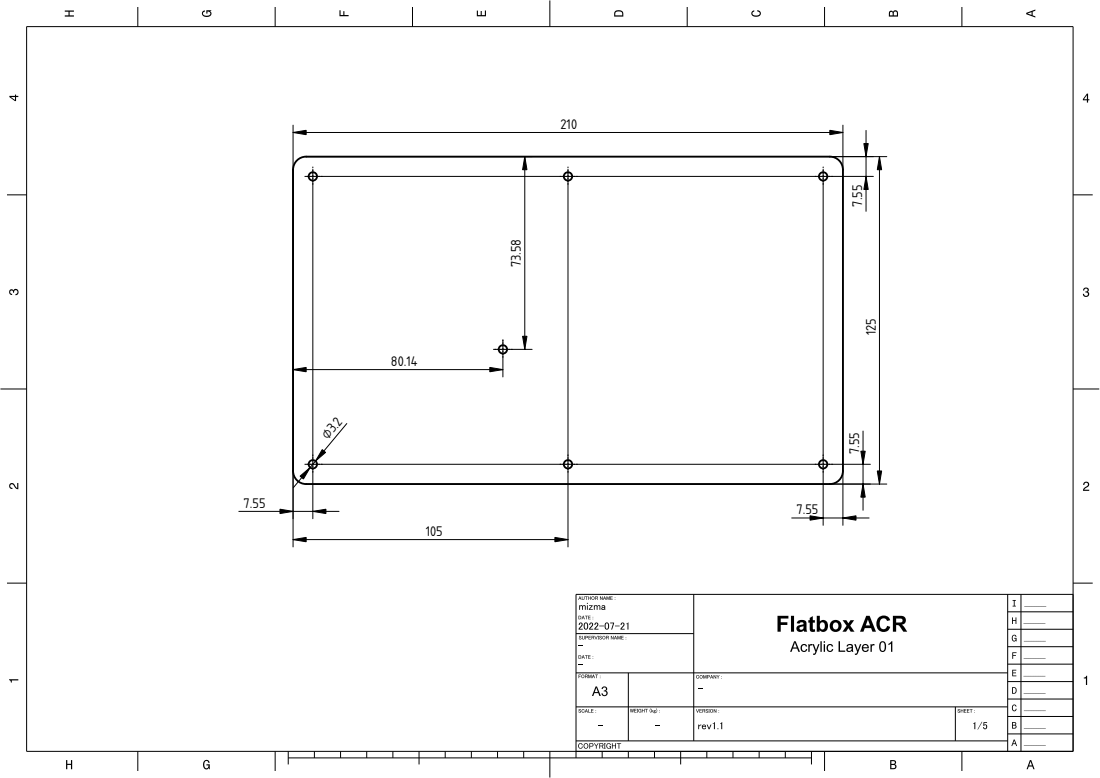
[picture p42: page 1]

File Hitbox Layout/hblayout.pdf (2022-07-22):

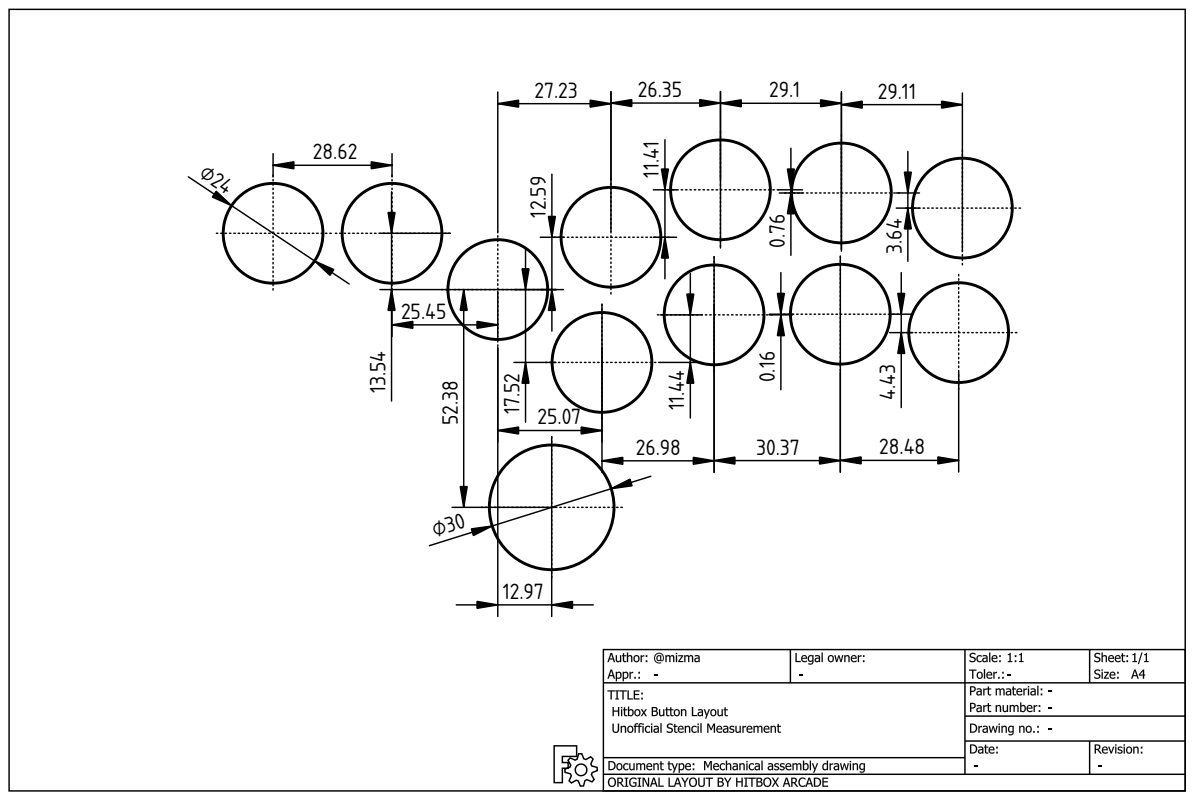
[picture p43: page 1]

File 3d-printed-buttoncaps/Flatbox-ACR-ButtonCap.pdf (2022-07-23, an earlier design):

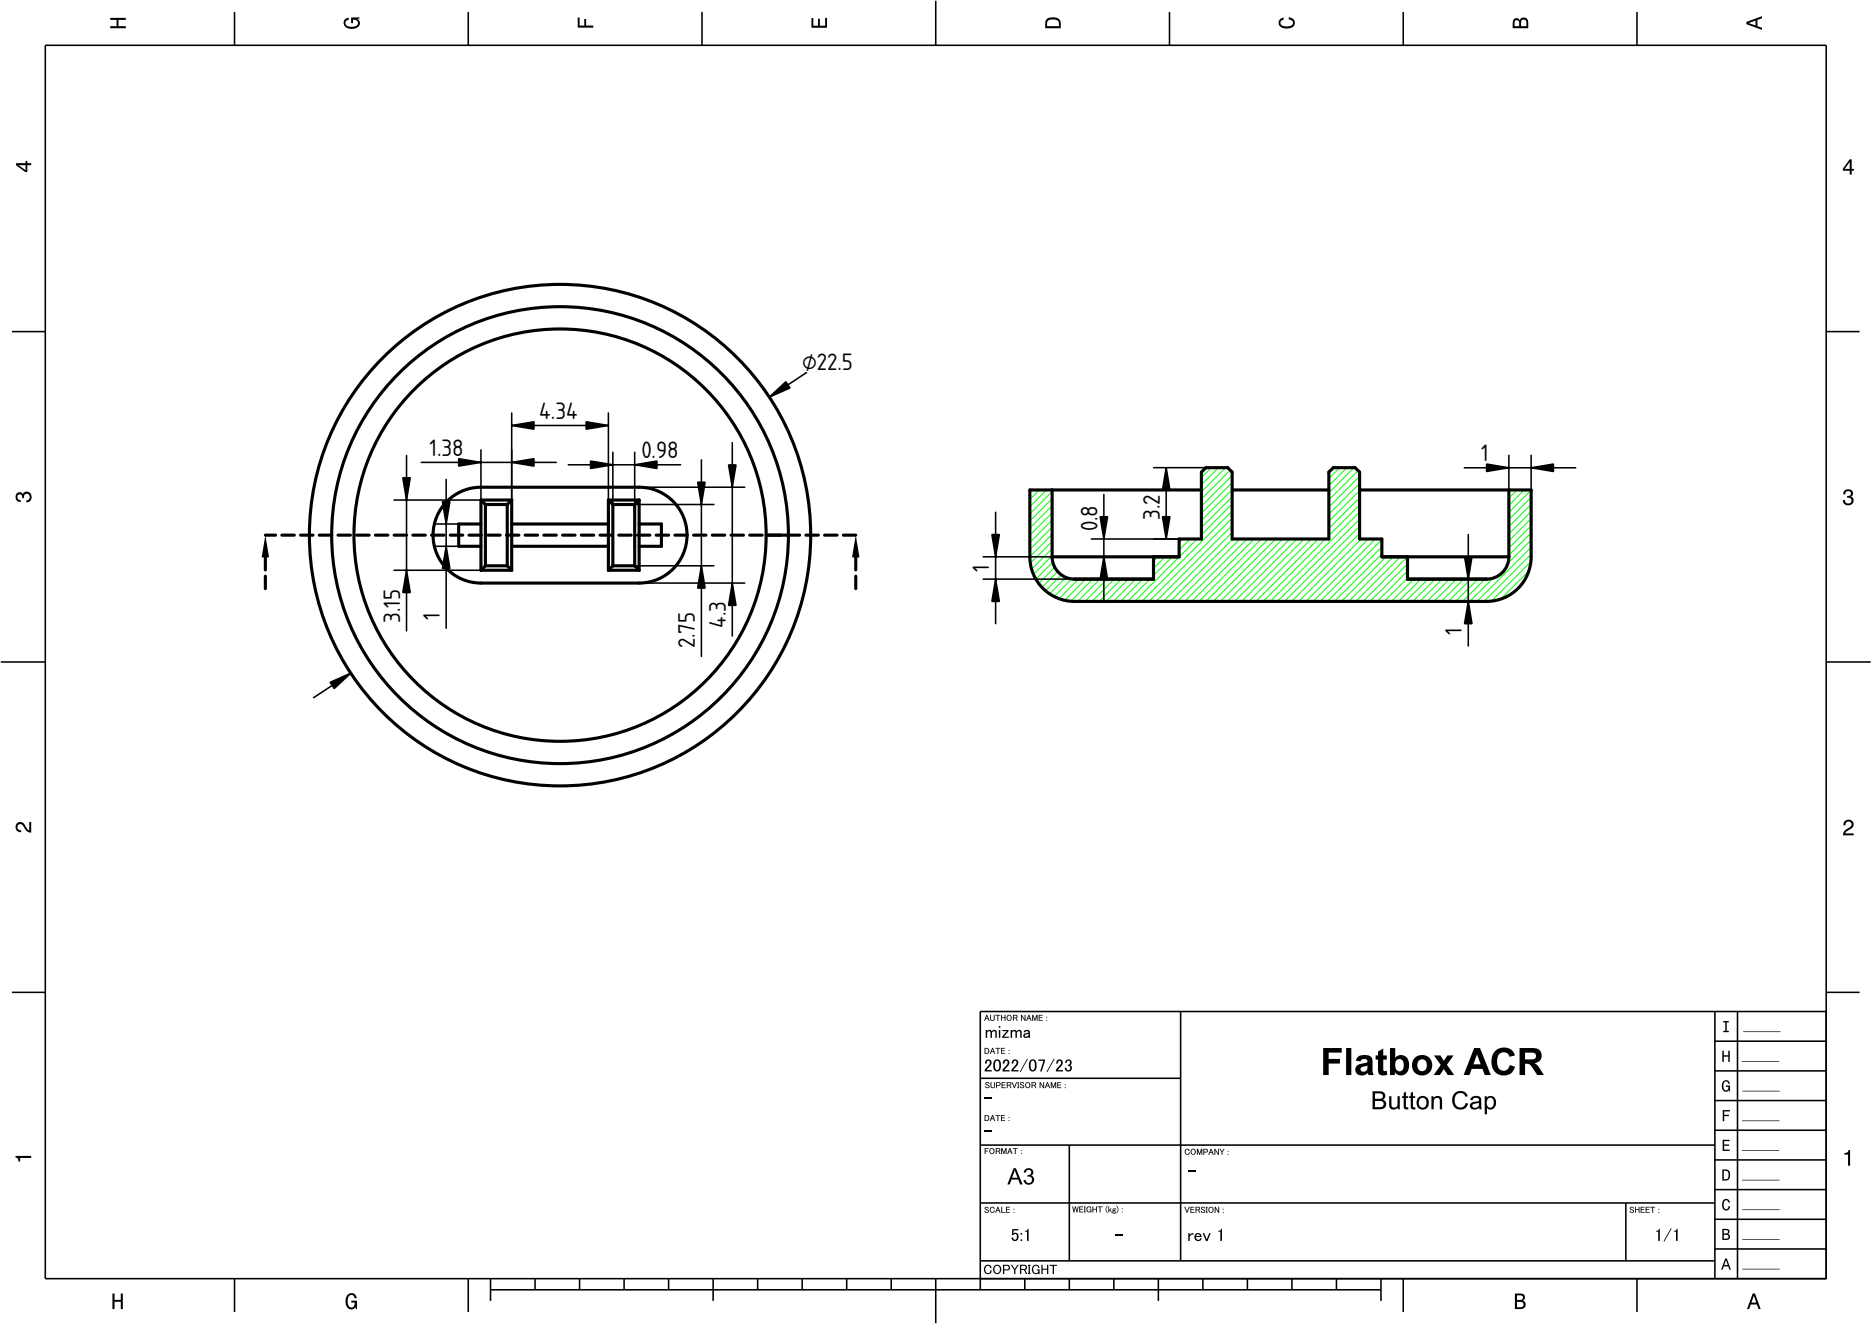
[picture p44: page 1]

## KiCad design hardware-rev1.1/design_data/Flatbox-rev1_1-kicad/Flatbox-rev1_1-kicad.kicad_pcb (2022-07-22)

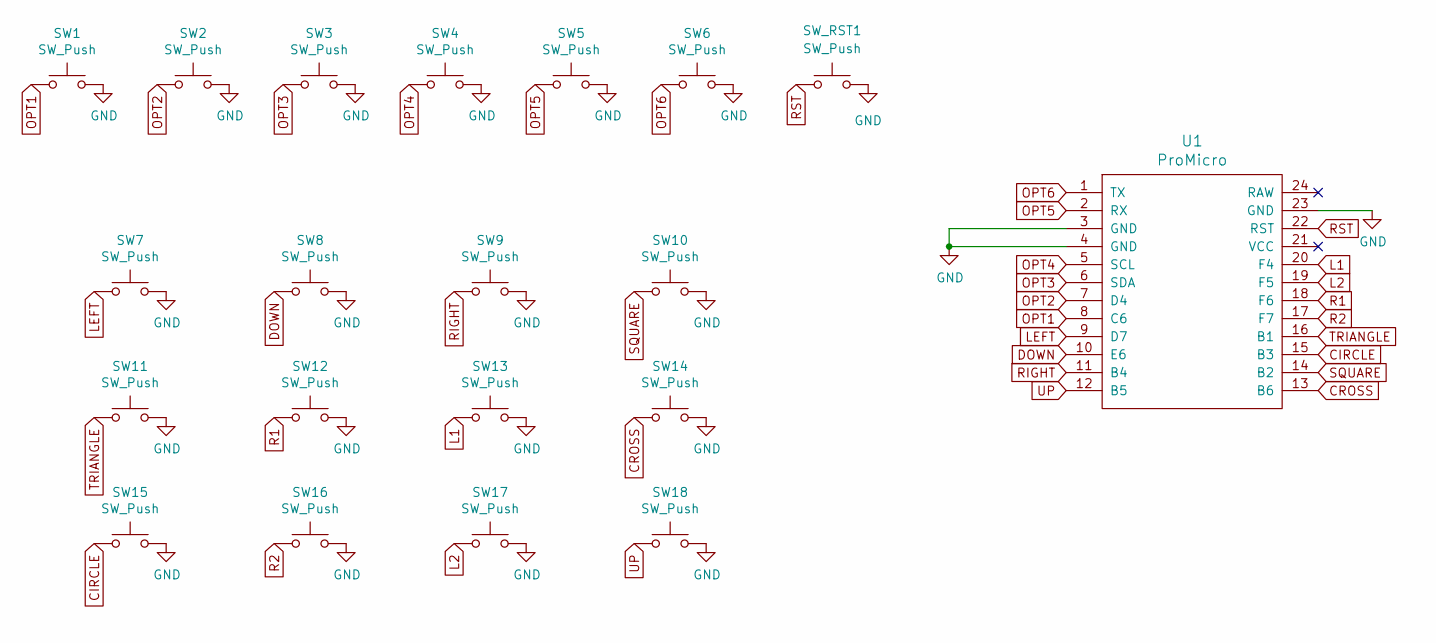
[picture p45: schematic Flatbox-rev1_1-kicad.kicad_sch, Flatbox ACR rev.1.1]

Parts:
SW1, SW2, SW3, SW4, SW5, SW6: SW_Push; SW_PUSH_6mm_H5mm
SW7, SW8, SW9, SW10, SW11, SW12, SW13, SW14, SW15, SW16, SW17, SW18: SW_Push; Kailh_socket_PG1350_optional
SW_RST1: SW_Push; SW_Tactile_Yushakobo 3x6x4.3mm
U1: ProMicro

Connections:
CIRCLE: SW15.1, U1.15 (B3)
CROSS: SW14.1, U1.13 (B6)
DOWN: SW8.1, U1.10 (E6)
GND: SW1.2, SW2.2, SW3.2, SW4.2, SW5.2, SW6.2, SW7.2, SW8.2, SW9.2, SW10.2, SW11.2, SW12.2, SW13.2, SW14.2, SW15.2, SW16.2, SW17.2, SW18.2, SW_RST1.2, U1.3 (GND), U1.4 (GND), U1.23 (GND)
L1: SW13.1, U1.20 (F4)
L2: SW17.1, U1.19 (F5)
LEFT: SW7.1, U1.9 (D7)
OPT1: SW1.1, U1.8 (C6)
OPT2: SW2.1, U1.7 (D4)
OPT3: SW3.1, U1.6 (SDA)
OPT4: SW4.1, U1.5 (SCL)
OPT5: SW5.1, U1.2 (RX)
OPT6: SW6.1, U1.1 (TX)
R1: SW12.1, U1.18 (F6)
R2: SW16.1, U1.17 (F7)
RIGHT: SW9.1, U1.11 (B4)
RST: SW_RST1.1, U1.22 (RST)
SQUARE: SW10.1, U1.14 (B2)
TRIANGLE: SW11.1, U1.16 (B1)
UP: SW18.1, U1.12 (B5)

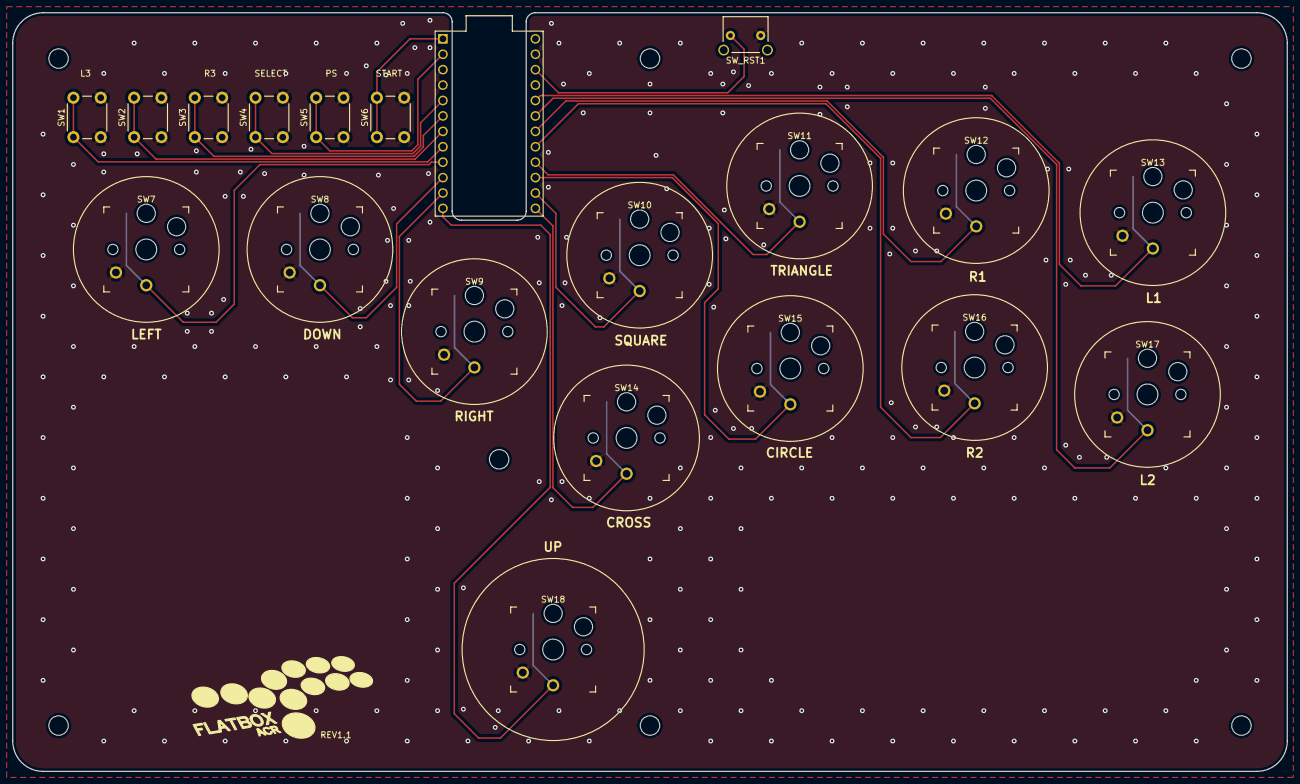
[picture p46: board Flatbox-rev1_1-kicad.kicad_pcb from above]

Board: 2 copper layers, 210.0 x 125.0 mm, 20 parts (0 on the bottom side), 20 nets.

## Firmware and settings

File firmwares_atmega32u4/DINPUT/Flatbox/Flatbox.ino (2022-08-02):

// Jacek Fedorynski <jfedor@jfedor.org>
// http://www.jfedor.org/

// Uncomment the appropriate line to match your stick version
#define REV1
//#define REV2

#include "HID.h"
#include <EEPROM.h>

#ifdef REV1

#define PIN_UP        9
#define PIN_DOWN      7
#define PIN_LEFT      6
#define PIN_RIGHT     8
#define PIN_CROSS     10
#define PIN_CIRCLE    14
#define PIN_TRIANGLE  15
#define PIN_SQUARE    16
#define PIN_L1        21
#define PIN_L2        20
#define PIN_R1        19
#define PIN_R2        18
#define PIN_SELECT    2
#define PIN_START     1
#define PIN_L3        5
#define PIN_R3        3
#define PIN_PS        0

#endif

#ifdef REV2

#define PIN_UP        5
#define PIN_DOWN      9
#define PIN_LEFT      8
#define PIN_RIGHT     10
#define PIN_CROSS     18
#define PIN_CIRCLE    21
#define PIN_TRIANGLE  14
#define PIN_SQUARE    7
#define PIN_L1        15
#define PIN_L2        19
#define PIN_R1        16
#define PIN_R2        20
#define PIN_SELECT    1
#define PIN_START     4
#define PIN_L3        3
#define PIN_R3        0
#define PIN_PS        6

#endif

int stickMode = 0; // 0 = dpad, 1 = left stick

// HID report descriptor taken from a HORI Fighting Stick V3
// works out of the box with PC and PS3
// as dumped by usbhid-dump and parsed by https://eleccelerator.com/usbdescreqparser/
static const uint8_t hidReportDescriptor[] PROGMEM = {
  0x05, 0x01,        // Usage Page (Generic Desktop Ctrls)
  0x09, 0x05,        // Usage (Game Pad)
  0xA1, 0x01,        // Collection (Application)
  0x85, 0x01,        // Report ID, not in the original descriptor, but the Arduino HID library can't seem to live without it
  0x15, 0x00,        //   Logical Minimum (0)
  0x25, 0x01,        //   Logical Maximum (1)
  0x35, 0x00,        //   Physical Minimum (0)
  0x45, 0x01,        //   Physical Maximum (1)
  0x75, 0x01,        //   Report Size (1)
  0x95, 0x0D,        //   Report Count (13)
  0x05, 0x09,        //   Usage Page (Button)
  0x19, 0x01,        //   Usage Minimum (0x01)
  0x29, 0x0D,        //   Usage Maximum (0x0D)
  0x81, 0x02,        //   Input (Data,Var,Abs,No Wrap,Linear,Preferred State,No Null Position)
  0x95, 0x03,        //   Report Count (3)
  0x81, 0x01,        //   Input (Const,Array,Abs,No Wrap,Linear,Preferred State,No Null Position)
  0x05, 0x01,        //   Usage Page (Generic Desktop Ctrls)
  0x25, 0x07,        //   Logical Maximum (7)
  0x46, 0x3B, 0x01,  //   Physical Maximum (315)
  0x75, 0x04,        //   Report Size (4)
  0x95, 0x01,        //   Report Count (1)
  0x65, 0x14,        //   Unit (System: English Rotation, Length: Centimeter)
  0x09, 0x39,        //   Usage (Hat switch)
  0x81, 0x42,        //   Input (Data,Var,Abs,No Wrap,Linear,Preferred State,Null State)
  0x65, 0x00,        //   Unit (None)
  0x95, 0x01,        //   Report Count (1)
  0x81, 0x01,        //   Input (Const,Array,Abs,No Wrap,Linear,Preferred State,No Null Position)
  0x26, 0xFF, 0x00,  //   Logical Maximum (255)
  0x46, 0xFF, 0x00,  //   Physical Maximum (255)
  0x09, 0x30,        //   Usage (X)
  0x09, 0x31,        //   Usage (Y)
  0x09, 0x32,        //   Usage (Z)
  0x09, 0x35,        //   Usage (Rz)
  0x75, 0x08,        //   Report Size (8)
  0x95, 0x04,        //   Report Count (4)
  0x81, 0x02,        //   Input (Data,Var,Abs,No Wrap,Linear,Preferred State,No Null Position)
  0x06, 0x00, 0xFF,  //   Usage Page (Vendor Defined 0xFF00)
  0x09, 0x20,        //   Usage (0x20)
  0x09, 0x21,        //   Usage (0x21)
  0x09, 0x22,        //   Usage (0x22)
  0x09, 0x23,        //   Usage (0x23)
  0x09, 0x24,        //   Usage (0x24)
  0x09, 0x25,        //   Usage (0x25)
  0x09, 0x26,        //   Usage (0x26)
  0x09, 0x27,        //   Usage (0x27)
  0x09, 0x28,        //   Usage (0x28)
  0x09, 0x29,        //   Usage (0x29)
  0x09, 0x2A,        //   Usage (0x2A)
  0x09, 0x2B,        //   Usage (0x2B)
  0x95, 0x0C,        //   Report Count (12)
  0x81, 0x02,        //   Input (Data,Var,Abs,No Wrap,Linear,Preferred State,No Null Position)
  0x0A, 0x21, 0x26,  //   Usage (0x2621)
  0x95, 0x08,        //   Report Count (8)
  0xB1, 0x02,        //   Feature (Data,Var,Abs,No Wrap,Linear,Preferred State,No Null Position,Non-volatile)
  0x0A, 0x21, 0x26,  //   Usage (0x2621)
  0x91, 0x02,        //   Output (Data,Var,Abs,No Wrap,Linear,Preferred State,No Null Position,Non-volatile)
  0x26, 0xFF, 0x03,  //   Logical Maximum (1023)
  0x46, 0xFF, 0x03,  //   Physical Maximum (1023)
  0x09, 0x2C,        //   Usage (0x2C)
  0x09, 0x2D,        //   Usage (0x2D)
  0x09, 0x2E,        //   Usage (0x2E)
  0x09, 0x2F,        //   Usage (0x2F)
  0x75, 0x10,        //   Report Size (16)
  0x95, 0x04,        //   Report Count (4)
  0x81, 0x02,        //   Input (Data,Var,Abs,No Wrap,Linear,Preferred State,No Null Position)
  0xC0,              // End Collection
};

typedef struct {
  uint16_t buttons; // bits: 0 = square, 1 = cross, 2 = circle, 3 = triangle,
                    // 4 = L1, 5 = R1, 6 = L2, 7 = R2, 8 = select, 9 = start,
                    // 10 = L3, 11 = R3, 12 = PS
  uint8_t dpadHat; // 0 = up, 1 = up/right, 2 = right etc., 0x0f = neutral
  uint8_t leftStickXAxis;
  uint8_t leftStickYAxis;
  uint8_t rightStickXAxis;
  uint8_t rightStickYAxis;
  uint8_t dpadRightAxis;
  uint8_t dpadLeftAxis;
  uint8_t dpadUpAxis;
  uint8_t dpadDownAxis;
  uint8_t triangleAxis;
  uint8_t circleAxis;
  uint8_t crossAxis;
  uint8_t squareAxis;
  uint8_t L1Axis;
  uint8_t L2Axis;
  uint8_t R1Axis;
  uint8_t R2Axis;
  uint16_t accelerometerXAxis; // 10 bits (these are guesses BTW)
  uint16_t accelerometerYAxis; // 10 bits
  uint16_t accelerometerZAxis; // 10 bits
  uint16_t gyroscopeAxis; // 10 bits
} hid_report_t;

hid_report_t report;
hid_report_t prevReport;
bool prevLeft;
bool prevRight;

typedef enum {
  HITBOX,   // UP&DOWN=UP, LEFT&RIGHT=NEUTRAL
  GAFRO,    // UP&DOWN=UP, LEFT&RIGHT=Last Input Wins
  NEUTRAL   // UP&DOWN=NEUTRAL, LEFT&RIGHT=NEUTRAL
} Socd_t;
Socd_t socd;

typedef enum {
  CMIDDLE_DOWN,     // Middle input is DOWN (Hitbox style)
  CMIDDLE_UP        // Middle input is UP (for normal arcade style)
} CardMiddle_t;
CardMiddle_t cmiddle;

void dpad_vinvert(bool, bool, bool, bool);
void dpad(bool, bool, bool, bool);

void (*dpad_p)(bool, bool, bool, bool);

void dpad_vinvert(bool up, bool down, bool left, bool right) {
  dpad(down, up, left, right);
}

void dpad(bool up, bool down, bool left, bool right) {
  if (up && down) {
    if (socd == NEUTRAL) {
      up = down = false; // neutral
    } else {
      down = false;   // Up always wins in Hitbox
    }
  }
  if (left && right) {
    if (socd == HITBOX || socd == NEUTRAL) {
      // SOCD cleaner: Hitbox (neutral in horizontal input)
      left = right = false;
    } else {
      // SOCD cleaner: Gafro (last input wins in horizontal input)
      if (prevLeft || prevRight) {
        // last one wins. (Not allowed in official tournaments)
        left = !prevLeft;
        right = !prevRight;
      } else {
        // If both came at the exact same time, keep neutral
        left = right = false;
      }
    }
  } else {
    prevLeft = left;
    prevRight = right;
  }

  switch (stickMode) {
    case 0:
      if (up && !right && !left) report.dpadHat = 0;
      else if (up && right) report.dpadHat = 1;
      else if (right && !up && !down) report.dpadHat = 2;
      else if (right && down) report.dpadHat = 3;
      else if (down && !right && !left) report.dpadHat = 4;
      else if (down && left) report.dpadHat = 5;
      else if (left && !down && !up) report.dpadHat = 6;
      else if (left && up) report.dpadHat = 7;
      else report.dpadHat = 0x0f;

      report.dpadRightAxis = right ? 0xff : 0x00;
      report.dpadLeftAxis = left ? 0xff : 0x00;
      report.dpadUpAxis = up ? 0xff : 0x00;
      report.dpadDownAxis = down ? 0xff : 0x00;
      break;
    case 1:
      report.leftStickXAxis = left ? 0x00 : (right ? 0xFF : 0x80);
      report.leftStickYAxis = up ? 0x00 : (down ? 0xFF : 0x80);
      break;
  }
}

void sendReport() {
  if (memcmp(&prevReport, &report, sizeof(report))) {
    HID().SendReport(1, &report, sizeof(report));
    memcpy(&prevReport, &report, sizeof(report));
  }
}

void setup() {
  static HIDSubDescriptor node(hidReportDescriptor, sizeof(hidReportDescriptor));
  bool updateSOCD = false;
  bool updateCMiddle = false;
  HID().AppendDescriptor(&node);

  pinMode(PIN_UP, INPUT_PULLUP);
  pinMode(PIN_DOWN, INPUT_PULLUP);
  pinMode(PIN_LEFT, INPUT_PULLUP);
  pinMode(PIN_RIGHT, INPUT_PULLUP);
  pinMode(PIN_CROSS, INPUT_PULLUP);
  pinMode(PIN_CIRCLE, INPUT_PULLUP);
  pinMode(PIN_TRIANGLE, INPUT_PULLUP);
  pinMode(PIN_SQUARE, INPUT_PULLUP);
  pinMode(PIN_L1, INPUT_PULLUP);
  pinMode(PIN_L2, INPUT_PULLUP);
  pinMode(PIN_R1, INPUT_PULLUP);
  pinMode(PIN_R2, INPUT_PULLUP);
  pinMode(PIN_SELECT, INPUT_PULLUP);
  pinMode(PIN_START, INPUT_PULLUP);
  pinMode(PIN_L3, INPUT_PULLUP);
  pinMode(PIN_R3, INPUT_PULLUP);
  pinMode(PIN_PS, INPUT_PULLUP);
  
  delay(500);

  // if LEFT is held when plugged in, switch to left stick emulation mode
  if (digitalRead(PIN_LEFT) == LOW) {
    stickMode = 1;
  }

  memset(&report, 0, sizeof(report));
  report.dpadHat = 0x0f;
  report.accelerometerXAxis = 0x02; // not sure why 0x02, but that's what HORI Fighting Stick V3 sends
  report.accelerometerYAxis = 0x02;
  report.accelerometerZAxis = 0x02;
  report.gyroscopeAxis = 0x02;
  report.leftStickXAxis = 0x80;
  report.leftStickYAxis = 0x80;
  report.rightStickXAxis = 0x80;
  report.rightStickYAxis = 0x80;
  memcpy(&prevReport, &report, sizeof(report));
  prevLeft = prevRight = false;

  // Read SOCD setting from EEPROM
  EEPROM.get(0, socd);

  if (socd != HITBOX && socd != GAFRO && socd != NEUTRAL) {
    // Initialize EEPROM
    socd = HITBOX;
    updateSOCD = true;
  }

  if (digitalRead(PIN_PS) == LOW) {
    // If PS is pressed, change to socd to NEUTRAL
    if (socd != NEUTRAL) {
      socd = NEUTRAL;
      updateSOCD = true;
    }
  }
  if (digitalRead(PIN_L3) == LOW) {
    // If L3 is pressed, change to socd to GAFRO
    if (socd != GAFRO) {
      socd = GAFRO;
      updateSOCD = true;
    }
  }
  if (digitalRead(PIN_R3) == LOW) {
    // If R3 is pressed, change to socd to HITBOX
    // If both are pressed, Hitbox setting wins
    if (socd != HITBOX) {
      socd = HITBOX;
      updateSOCD = true;
    }
  }

  if (updateSOCD) {
    // Update EEPROM data
    EEPROM.put(0, socd);
  }

  // Default is middle button = down.
  dpad_p = dpad;

  EEPROM.get(2, cmiddle);

  if (cmiddle != CMIDDLE_DOWN && cmiddle != CMIDDLE_UP) {
    // Initialize to Hitbox style if EEPROM is not initialized
    cmiddle = CMIDDLE_DOWN;
    updateCMiddle = true;
  }

  if (digitalRead(PIN_UP) == LOW) {
    // set to standard arcade style setup
    if  (cmiddle != CMIDDLE_UP) {
      cmiddle = CMIDDLE_UP;
      updateCMiddle = true;
    }
  }
  if (digitalRead(PIN_DOWN) == LOW) {
    // set to standard Hitbox style setup
    if  (cmiddle != CMIDDLE_DOWN) {
      cmiddle = CMIDDLE_DOWN;
      updateCMiddle = true;
    }
  }

  if (updateCMiddle) {
    EEPROM.put(2, cmiddle);
  }

  if (cmiddle == CMIDDLE_UP) {
    // if CMIDDLE_UP is set, re-point the dpad_p pointer to an invert function
    dpad_p = dpad_vinvert;
  }
}

void loop() {
  report.buttons = 0x00;
  report.triangleAxis = 0x00;
  report.circleAxis = 0x00;
  report.crossAxis = 0x00;
  report.squareAxis = 0x00;
  report.L1Axis = 0x00;
  report.L2Axis = 0x00;
  report.R1Axis = 0x00;
  report.R2Axis = 0x00;

  dpad_p(digitalRead(PIN_UP) == LOW,
       digitalRead(PIN_DOWN) == LOW,
       digitalRead(PIN_LEFT) == LOW,
       digitalRead(PIN_RIGHT) == LOW);

  if (digitalRead(PIN_SQUARE) == LOW) {
    report.buttons |= 1 << 0;
    report.squareAxis = 0xff;
  }
  if (digitalRead(PIN_CROSS) == LOW) {
    report.buttons |= 1 << 1;
    report.crossAxis = 0xff;
  }
  if (digitalRead(PIN_CIRCLE) == LOW) {
    report.buttons |= 1 << 2;
    report.circleAxis = 0xff;
  }
  if (digitalRead(PIN_TRIANGLE) == LOW) {
    report.buttons |= 1 << 3;
    report.triangleAxis = 0xff;
  }
  if (digitalRead(PIN_L1) == LOW) {
    report.buttons |= 1 << 4;
    report.L1Axis = 0xff;
  }
  if (digitalRead(PIN_R1) == LOW) {
    report.buttons |= 1 << 5;
    report.R1Axis = 0xff;
  }
  if (digitalRead(PIN_L2) == LOW) {
    report.buttons |= 1 << 6;
    report.L2Axis = 0xff;
  }
  if (digitalRead(PIN_R2) == LOW) {
    report.buttons |= 1 << 7;
    report.R2Axis = 0xff;
  }
  if (digitalRead(PIN_SELECT) == LOW) {
    report.buttons |= 1 << 8;
  }
  if (digitalRead(PIN_START) == LOW) {
    report.buttons |= 1 << 9;
  }
  if (digitalRead(PIN_L3) == LOW) {
    report.buttons |= 1 << 10;
  }
  if (digitalRead(PIN_R3) == LOW) {
    report.buttons |= 1 << 11;
  }
  if (digitalRead(PIN_PS) == LOW) {
    report.buttons |= 1 << 12;
  }

  sendReport();
}

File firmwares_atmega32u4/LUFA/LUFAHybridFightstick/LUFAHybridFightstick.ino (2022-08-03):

#include "LUFAConfig.h"
#include <LUFA.h>
#include "XS_HID.h"
#define BOUNCE_WITH_PROMPT_DETECTION
#include <Bounce2.h>
#include <EEPROM.h>
#include <inttypes.h>

/* in case you want to disable one type of gamepad */
//#define DISABLE_NSWITCH
//#define DISABLE_XINPUT

#define SOCD_CONFIG

/* PINOUT (follows Nintendo naming (X=up, B=down)) */
#define PIN_UP    9
#define PIN_DOWN  7
#define PIN_LEFT  6
#define PIN_RIGHT 8
#define PIN_A     MISO         //XBOX B
#define PIN_B     10           //XBOX A  
#define PIN_X     15           //XBOX Y
#define PIN_Y     MOSI         //XBOX X     
#define PIN_L     21           //XBOX LB
#define PIN_R     19           //XBOX RB
#define PIN_ZL    20           //XBOX LT
#define PIN_ZR    18           //XBOX RT
#define PIN_LS    5            //XBOX LS (left analog click)
#define PIN_RS    3            //XBOX RS (right analog click)
#define PIN_PLUS  1            //XBOX START
#define PIN_MINUS 2            //XBOX BACK
#define PIN_HOME  0

/* Buttons declarations */
#define MILLIDEBOUNCE 1 //Debounce time in milliseconds
unsigned long startAndSelTime = 0;
unsigned long currTime = 0;

byte internalButtonStatus[4];

Bounce joystickUP = Bounce();
Bounce joystickDOWN = Bounce();
Bounce joystickLEFT = Bounce();
Bounce joystickRIGHT = Bounce();
Bounce buttonA = Bounce();
Bounce buttonB = Bounce();
Bounce buttonX = Bounce();
Bounce buttonY = Bounce();
Bounce buttonL = Bounce();
Bounce buttonR = Bounce();
Bounce buttonZL = Bounce();
Bounce buttonZR = Bounce();
Bounce buttonLS = Bounce();
Bounce buttonRS = Bounce();
Bounce buttonPLUS = Bounce();
Bounce buttonMINUS = Bounce();
Bounce buttonHOME = Bounce();

/* MODE DECLARATIONS */
typedef enum {
  RIGHT_ANALOG_MODE,
  ANALOG_MODE,
  DIGITAL,
} State_t;
State_t state;

typedef enum {
  NEUTRAL,    // LEFT/UP + DOWN/RIGHT = NEUTRAL
  NEGATIVE,   // LEFT/UP beats DOWN/RIGHT
  POSITIVE,   // DOWN/RIGHT beats LEFT/UP
  LAST_INPUT, //Last input has priority; not a valid state if being used for initial_input
} Socd_t;
Socd_t x_socd_type = NEUTRAL; // controls left/right and up/down resolution type
Socd_t y_socd_type = NEGATIVE;
Socd_t x_initial_input, y_initial_input = NEUTRAL;

typedef enum {
  CVERT_NORMAL,     // Middle input is DOWN (Hitbox style)
  CVERT_INVERT        // Middle input is UP (for normal arcade style)
} CardVert_t;
CardVert_t cvert;

/* mode selectors */
bool xinput;
bool modeChanged;

void checkModeChange() {
  if (buttonStatus[BUTTONSTART] && buttonStatus[BUTTONSELECT])
  {
    if ( !modeChanged )
    {
      State_t last_state;

      last_state = state; 

      if (internalButtonStatus[BUTTONLEFT])
        state = ANALOG_MODE;
      else if (internalButtonStatus[BUTTONRIGHT])
        state = RIGHT_ANALOG_MODE;
      else if (internalButtonStatus[BUTTONUP])
        state = DIGITAL;

      if (last_state != state) EEPROM.put(0, state);
      modeChanged = true;
    }
    else
    {
      modeChanged = false;
    }
  }
}

void setupPins() {
  if (cvert == CVERT_INVERT) {
    // Inverted Up/Down input
    joystickUP.attach(PIN_DOWN, INPUT_PULLUP);
    joystickDOWN.attach(PIN_UP, INPUT_PULLUP);
  } else { // CVERT_NORMAL (Default)
    joystickUP.attach(PIN_UP, INPUT_PULLUP);
    joystickDOWN.attach(PIN_DOWN, INPUT_PULLUP);
  }
  joystickLEFT.attach(PIN_LEFT, INPUT_PULLUP);
  joystickRIGHT.attach(PIN_RIGHT, INPUT_PULLUP);
  buttonA.attach(PIN_A, INPUT_PULLUP);     // XBOX B
  buttonB.attach(PIN_B, INPUT_PULLUP);     // XBOX A
  buttonX.attach(PIN_X, INPUT_PULLUP);     // XBOX Y
  buttonY.attach(PIN_Y, INPUT_PULLUP);    // XBOX X
  buttonL.attach(PIN_L, INPUT_PULLUP);    // XBOX LB
  buttonR.attach(PIN_R, INPUT_PULLUP);     // XBOX RB
  buttonZL.attach(PIN_ZL, INPUT_PULLUP);    // XBOX LT
  buttonZR.attach(PIN_ZR, INPUT_PULLUP);    // XBOX RT
  buttonLS.attach(PIN_LS, INPUT_PULLUP);       // XBOX LS
  buttonRS.attach(PIN_RS, INPUT_PULLUP);       // XBOX RS
  buttonPLUS.attach(PIN_PLUS, INPUT_PULLUP);   // XBOX START
  buttonMINUS.attach(PIN_MINUS, INPUT_PULLUP); // XBOX BACK
  buttonHOME.attach(PIN_HOME, INPUT_PULLUP);

  joystickUP.interval(MILLIDEBOUNCE);
  joystickDOWN.interval(MILLIDEBOUNCE);
  joystickLEFT.interval(MILLIDEBOUNCE);
  joystickRIGHT.interval(MILLIDEBOUNCE);
  buttonA.interval(MILLIDEBOUNCE);
  buttonB.interval(MILLIDEBOUNCE);
  buttonX.interval(MILLIDEBOUNCE);
  buttonY.interval(MILLIDEBOUNCE);
  buttonL.interval(MILLIDEBOUNCE);
  buttonR.interval(MILLIDEBOUNCE);
  buttonZL.interval(MILLIDEBOUNCE);
  buttonZR.interval(MILLIDEBOUNCE);
  buttonLS.interval(MILLIDEBOUNCE);
  buttonRS.interval(MILLIDEBOUNCE);
  buttonPLUS.interval(MILLIDEBOUNCE);
  buttonMINUS.interval(MILLIDEBOUNCE);
  buttonHOME.interval(MILLIDEBOUNCE);
}

void setup() {

  bool updateCVert = false;
  modeChanged = false;
  EEPROM.get(0, state);
  EEPROM.get(2, xinput);
#ifdef SOCD_CONFIG
  EEPROM.get(4, x_socd_type);
  EEPROM.get(6, y_socd_type);
#endif

  // setup cardinal middle button settings
  EEPROM.get(8, cvert);

  if (cvert != CVERT_NORMAL && cvert != CVERT_INVERT) {
    // Initialize to Hitbox style if EEPROM is not initialized
    cvert = CVERT_NORMAL;
    updateCVert = true;
  }

  if (digitalRead(PIN_UP) == LOW) {
    // set to standard arcade style setup
    if  (cvert != CVERT_INVERT) {
      cvert = CVERT_INVERT;
      updateCVert = true;
    }
  }
  if (digitalRead(PIN_DOWN) == LOW) {
    // set to standard Hitbox style setup
    if  (cvert != CVERT_NORMAL) {
      cvert = CVERT_NORMAL;
      updateCVert = true;
    }
  }

  if (updateCVert) {
    EEPROM.put(8, cvert);
  }

  setupPins();
  delay(500);

#ifdef DISABLE_NSWITCH
#warning "NSWITCH mode is disabled, will act only as an XInput controller"
  /* force Xinput */
  xinput = true;
#else
#ifdef DISABLE_XINPUT
#warning "XINPUT mode is disabled, will act only as a Nintendo switch controller"
  /* force nswitch */
  xinput = false;
#else
  /* set xinput mode according to held button */
  // if select is held on boot, NSWitch mode
  bool xinput_current = xinput;
  int value = digitalRead(PIN_MINUS);
  if (value == LOW)
  {
    xinput = false;
  }
  // if start is held on boot, XInput mode
  else {
    value = digitalRead(PIN_PLUS);
    if (value == LOW)
    {
      xinput = true;
    }
  }
  if (xinput_current != xinput) {
    // Update if changed
    EEPROM.put(2, xinput);
  }
#endif
#endif

  // TODO: add setting for inverting Up/Down
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

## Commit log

2022-07-19 added STL for full set print orders. added logo for front silk
    [FullSetButtonCaps.FCStd, FullSetButtonCaps.stl]
2022-07-19 moved original design files to original-hardware directory
    [Flatbox-rev1.1-Bottom-hotswap.stl, Flatbox-rev1.1-Bottom.stl, Flatbox-rev1.1-Top.stl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]
2022-07-19 moved supporting files to original-hardware directory
    [Buttoncap.stl, ButtoncapBig.stl, FullSetButtonCaps.FCStd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]
2022-07-19 fixed README for nuances. added PCB image
2022-07-19 added acrylic cut data and gerber files for PCB. update Readme.
    [acryl-design-Flatbox-ACR-Acrylic-layer-01.dxf, acryl-design-Flatbox-ACR-Acrylic-layer-02.dxf, acryl-design-Flatbox-ACR-Acrylic-layer-03.dxf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]
2022-07-19 fix layout issues in dxf
    [acryl-design-Flatbox-ACR-Acrylic-layer-02.dxf, acryl-design-Flatbox-ACR-Acrylic-layer-03.dxf, acryl-design-Flatbox-ACR-Acrylic-layer-04.dxf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]
2022-07-19 fixed some issues with acrylic cut and edge cut on PCB
2022-07-19 add design data
    [Flatbox-rev1-kicad.kicad_pcb, Flatbox-rev1-kicad.kicad_sch, Flatbox-rev1-kicad.sch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]
2022-07-19 update logo
    [Flatbox-rev1-kicad.kicad_pcb]
2022-07-22 remove rev1 data. abandoned
    [Flatbox-rev1-kicad.kicad_pcb, Flatbox-rev1-kicad.kicad_sch, Flatbox-rev1-kicad.sch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]
2022-07-22 add hardware rev1.1 design
    [Flatbox-rev1_1-kicad-B_Cu.gbl, Flatbox-rev1_1-kicad-B_Mask.gbs, Flatbox-rev1_1-kicad-B_Paste.gbp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]
2022-07-22 fix acryl layer naming. added missing measurements in button layout file.
    [hblayout.FCStd]
2022-07-22 added buttoncap drawing
2022-07-23 first draft of Flatbox ACR ButtonCap
    [Flatbox-ACR-ButtonCap.FCStd, Flatbox-ACR-ButtonCap.stl, Flatbox-ACR-ButtonCapBig.FCStd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]
2022-07-23 fixed stl mesh. added fullset stl file
    [Flatbox-ACR-ButtonCap.FCStd, Flatbox-ACR-ButtonCap.stl, Flatbox-ACR-ButtonCapBig.stl]
2022-07-23 remove original Flatbox buttoncaps (not applicable to ACR version)
    [Buttoncap.stl, ButtoncapBig.stl, FullSetButtonCaps.FCStd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]
2022-07-31 fix SOCD and add GAFRO as well as reverse Up/Down feature
    [Flatbox.ino]
2022-08-02 remove analog code, fix SOCD Config.
    [LUFAHybridFightstick.ino]
2022-08-02 fix some old README text to match current implementation
2022-08-09 added image with button caps. tweak button height.
    [Flatbox-ACR-ButtonCap.FCStd, Flatbox-ACR-ButtonCapBig.FCStd, Flatbox-ACR-ButtonCapBig_rev1.1.stl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]
2022-08-09 update on button caps.
2022-09-01 revised rev1.1 to remove unnecessary extrusion
    [Flatbox-ACR-ButtonCap.FCStd, Flatbox-ACR-ButtonCapBig.FCStd, Flatbox-ACR-ButtonCapBig_rev1.1.stl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]
